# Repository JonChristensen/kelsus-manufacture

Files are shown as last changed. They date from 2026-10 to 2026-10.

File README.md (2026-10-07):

# The Kelsus Manufacture — open-source, 3D-printable watch movements

**Nobody has published a working, printable, conventional watch movement designed
as a platform for complications. This project builds them — in public.**

The movements are the road, not the destination. The destination is two
complications that don't exist yet in mechanical horology:

1. **A haptic metronome** — taps your wrist at an adjustable musical tempo,
   powered by its own dedicated mainspring barrel (the architecture of
   mechanical alarm watches like the Vulcain Cricket, pointed at a new job).
   This is **Caliber K2**.
2. **A world-class tide indication** — going beyond every existing tide watch
   (Corum, IWC, CVDK all model a single tidal constituent) by mechanically
   summing a second constituent — the "priming and lagging" of the tides —
   plus perigean spring tides via an anomalistic-month cam.

Everything is **parametric Python ([build123d](https://github.com/gumyr/build123d))**:
the CAD is code, every dimension traces to a parameters file, every design
decision is a reviewable git diff, and geometry is unit-tested in CI before
any printer wastes plastic.

Like a real manufacture, this repo holds multiple calibers sharing one
engine (`movement/` — cycloidal gears, the sweep solver, the spring model):

| Caliber | What | Status |
|---|---|---|
| [**K1**](calibers/k1/) | Time + moon phase; the proven base movement | **First physical build underway** — rev C is printing; dry-train assembly next (PETG flexures to follow) |
| [**K2**](calibers/k2/) | Time + the haptic metronome | Two-sided layout frozen; winding link solved (log 0023); parts stage next |

Scale: these are desk-scale movements (Ø170 mm mainplate) — watch architecture
at a size FDM printing genuinely masters, with a metal-transferable topology
(K2's target is a 44×15 mm wristwatch case). Proven precedent: [Christoph
Laimer's printed tourbillon](https://www.thingiverse.com/thing:1249221)
(Ø102 mm, runs).

The ocean — the tide complication's destination — lives in the frame itself:
K1's train bridge is a breaking wave, and the wheels spin on whirlpool spokes.

the wave bridge

## Build it

```bash
python3 -m venv .venv && .venv/bin/pip install -r requirements.txt
.venv/bin/python -m pytest tests/            # the geometry gate (runs in CI)
.venv/bin/python tools/export_print_kit.py   # K1 print kit -> exports/k1/print/
.venv/bin/python tools/render_previews.py    # PNG previews of every part
```

Print from [`exports/k1/print/`](exports/k1/print/MANIFEST.md): the MANIFEST
carries per-part orientation, support maps and quantities; the
[printing guide](docs/k1/printing-guide.md) carries the bench-proven Bambu
Studio settings. Curated, support-painted Bambu plates live in
[`exports/k1/print/plates/`](exports/k1/print/plates/README.md). Then follow
the [assembly guide](docs/k1/assembly-guide.md) — stage by stage, each with
its own inspection gate, from mainspring to a regulated tick.

## Repository layout

- `movement/` — the shared engine: cycloidal gear generator, sweep solver,
  spring energy model. Caliber-agnostic by rule.
- `calibers/k1/` — Caliber K1 rev C: parameters, layout solver, parts, dial
  side, the traced wave bridge
- `calibers/k2/` — Caliber K2: frozen brief + metal target, the two-sided
  layout, the one-crown/two-position winding link
- `attic/` — superseded generations, kept buildable and tested: the rev A
  storey tower, the rev B flatten, K2's round-plate era
- `exports/` — print kits and review STEPs, per caliber (latest per line;
  history keeps the rest)
- `docs/log/` — the engineering journal (decisions and why), one unified
  timeline across calibers; `docs/k1/` — build guides, milestones, registers
- `tests/` — the geometry gate: clearances, mesh ratios, stack heights,
  assembled poses. CI runs it on every push.
- `tools/` — exporters and massing/review builders

## Licensing

Two permissive licenses, chosen so anyone can build a business on these
movements without asking us or paying us.

- **Hardware designs** (everything under `movement/`, `calibers/`, and
  `attic/`, plus the generated STEP/STL geometry):
  [CERN-OHL-P v2](LICENSE), the permissive variant of CERN's
  open hardware license. You can manufacture the movement, sell it, modify it,
  and keep your modifications closed. It carries an explicit patent grant, which
  a copyright-only license like CC0 or CC BY does not, and that grant is what
  protects a functional mechanical design. No reciprocity, no share-alike, no
  obligation to credit us on the movement.
- **Tooling** (`tools/`, CI): [MIT](LICENSE-MIT).

This is a deliberately more open position than the current open watch movement,
[openmovement's OM10](https://openmovement.org/project/om10/). The OM10 is
copyleft (CC BY-SA 3.0): it requires you to engrave its calibre number on the
movement, requires your derivatives to carry the same license, and reserves the
production 2D/3D data for sale under its own purchase terms. This manufacture
asks for none of that. Take the geometry, put it in a product, sell the
product, and you owe us nothing.

## Follow along

Build-in-public links (site, TikTok, videos) land here as they go live.

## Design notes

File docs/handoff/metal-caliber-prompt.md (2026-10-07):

# Handoff prompt — design the 36 mm metal base caliber

*Paste everything below the line into a new conversation that has this repo open. It was written on Oct 7 2026 at the end of a long session on the plastic K1; the plastic work continues in a separate conversation. Keep both from editing the same files — see "Working arrangement".*

---

You are taking over the design of an **open-source mechanical wristwatch caliber in metal** from a conversation that spent four months building its 5×-scale plastic prototype. This document is the whole context you have: the goal, what exists, what was learned, what was decided, what is still open, and the plan. Read it fully, then read the repo files it points to, before proposing anything.

## 1. Who you are working with

Jon (jon@kelsus.com) is a self-described CAD novice who directs, prints and tests; you drive the CAD. He owns a Bambu Lab H2C printer (350 × 320 mm bed) and builds in public (GitHub, website, TikTok). His construction instincts about real watches — from studying the NH35, ETA 2824 and 6497 — have repeatedly out-corrected the model's; when he says a real movement does it another way, verify yours against the real caliber before defending it. His eyes are a required gate: every design step ends with an "inspect this" checklist and a rendered picture he can judge.

The memory directory for this project (loaded automatically as `MEMORY.md`) holds the standing lessons. Read it; the entries `feedback-target-is-watch-scale`, `k1-rev-b-flatten`, `inspection-gates`, `cad-workflow-choice` and `k1-revc-status` matter most here.

## 2. The goal, stated plainly

A **truly open, free-for-anyone wristwatch base caliber** — Jon's own design including the base, with no license strings, no branding requirement, no membership gate (OpenMovement's OM10 was considered and rejected on exactly those grounds). On that base, later, complications that do not exist in horology: a **haptic metronome** (Caliber K2's job; the metronome keeps its own barrel) and a **world-class tide indication**. The complications are years away and are not your job now. The base is.

"Open" for hardware means: every drawing free; every part either makeable from the drawings or a commodity anyone can buy from more than one source. Nobody — not independents, not most Swiss brands — makes hairsprings, jewels or mainsprings. So:

- **v1:** everything is Jon's except the regulating consumables, which are bought as a multi-source assortment.
- **v2:** Jon's own escapement and balance, once v1 keeps time.

## 3. Decisions already made (Oct 7 2026) — do not reopen without new evidence

| Decision | Value | Why |
|---|---|---|
| Size class | **36 mm** (6497-class), fits a 42 mm case at the floor, 43–44 comfortable | Complications need plate; main train stays near module 0.2; plastic model at a clean 5×; hand-fitting margin for a first-time maker |
| Beat | **4 Hz, 28,800 bph** | Industry sweet spot; the most open frequency on earth. 5 Hz was wanted and declined: f³ power cost, lubrication demands, and no multi-source 5 Hz assortment exists |
| Regulating organ, v1 | **ETA 2824-class assortment**: balance complete + hairspring, pallet fork, escape wheel, shock protection, jewels — made by ETA, cloned by Sellita (SW200) and Seagull (ST2130), stocked aftermarket | Design the balance cock, escapement positions and jewel seats so these parts drop in. A big plate with a small fast balance is normal manufacture practice |
| Power reserve | ≥ 40 h from a Ø16-class barrel; the metronome gets its own barrel later | 4 Hz with a big barrel lands 40–50 h |
| Thickness | base 5–6 mm; expect 13–15 mm cases once modules stack | Tell Jon before anything grows it |
| Plastic's role | a **5× kinematic model derived from the 1× design**, never the other way round | The old mistake was a print-first geometry with a "metal variant" that was the same Ø150 plate in brass — a clock nobody wanted |
| Source of truth | build123d code in git, parametric, with pytest gates and CI; export → render → look at the PNG before calling anything done | Memory: `cad-workflow-choice` |

## 4. What exists in the repo

Layout (`README.md` is current): `movement/` is the shared engine — `gears.py` (cycloidal wheel/pinion faces: `wheel_face`, `pinion_face`, hypocycloid gullets, BS978 addenda, backlash), `solver.py` (the station/sweep layout solver — read `docs/how-the-solver-works.md`), `springs.py`. `calibers/k1/` is the plastic K1 rev C (time + moon phase): `revc.py` (frozen layout, counts, `ESC_TUNE`, `TOOTH`, `WINDING`, the chirality chain), `revc_parts.py` (every part builder), `revc_dial.py`/`revc_dial_parts.py` (dial side: indirect minute via a 3-mesh transfer chain, motion works and a 59.0625-ratio moon train in dial-face recesses), `variants.py` (the print/metal dimension tables — see §6), `decor.py`, `wave_art.py`. `calibers/k2/` is the metronome caliber's brief and layout (Ø250 two-sided massing, winding link solved). `attic/` holds rev A/B. `tools/` holds the exporters (`export_print_kit.py` generates `exports/k1/print/MANIFEST.md` — never edit the .md), the STEP builder (`build_revc_movement.py`), and the **kinematic probes** that are the project's real instruments: `probe_escapement.py` (sections built solids to 2D with shapely and simulates the lock/unlock/tick with the wheel torque-butted), `probe_fork.py` (roller pin through the fork horns), `probe_click.py`, `probe_winding.py`. `tests/test_revc_parts.py` is ~100 gates run in CI (`.github/workflows/ci.yml`); as of Oct 7 the suite is 106 passed, 3 xfailed (the xfails record the broken keyless works).

Read, in this order: `README.md`, `docs/log/0016-rev-c-expert-brief.md` (how a brief is written and why top-down matters), `docs/log/0025`–`0028` (what the bench taught), `calibers/k1/revc.py`, `calibers/k1/variants.py`, `docs/how-the-solver-works.md`, `tests/test_revc_parts.py`.

## 5. The honest assessment of K1 as a watch caliber

**Architecture: right, keep it.** Two-plate construction; offset going barrel hanging from the plate with a bridge-web bearing; an interleaved two-plane train with a true 60 s fourth arbor; Swiss lever; keyless works with ratchet and crown wheel at the bridge plane; motion works and moon train in dial-side recesses with a retaining platform (only the hour wheel stands proud); a decorative bridge that is a real train bridge. Jon's corrections drove it there and it maps onto real construction.

**Proportions: plastic's, discard.** Every number was chosen to survive a 0.4 mm nozzle: module 1 teeth with 6- and 7-leaf pinions at the packing limit; a 16-tooth escape wheel at ~0.5 Hz on a 30 s/rev arbor; a 2:1 last stage; Ø2.5 pivots in printed cups and a shoulder-on-shelf endshake system with blind bridge bearings; a 14 g balance trimmed with M3 nuts; a fork with integral stones built to a print envelope; a PETG mainspring sized at PETG's strain limit; a pull-pawl click. None transfer.

**The gap: there is no 1× design yet.** `variants.py`'s "metal" entry is the Ø150 geometry with metal clearances and a 30-tooth escape wheel giving 1 Hz. A 1 Hz wristwatch is shock-sensitive and positionally unstable. The variant switch was meant to stop the project "getting married to the printable version and flying blind at the CNC handoff"; it never got a scale, so it guarded nothing. **Your first structural job is to make 1× the source of truth and derive the print model from it.**

**Train arithmetic you will redo.** K1 counts are `(60, 10, 56, 7, 45, 6, 36, 18)` = barrel 60 → center pinion 10 (6:1, center at 1 h/rev) → center wheel 56 → third pinion 7 (8:1) → third wheel 45 → fourth pinion 6 (7.5:1, fourth at 60 s/rev) → fourth wheel 36 → escape pinion 18 (2:1). Barrel-to-escape is 720:1. At 4 Hz the escape wheel's revolution time is set by the assortment's tooth count (take it from the real part — measure a 2824/SW200 or use published service data; do not trust memory for the 2824's counts, lift angle or center distances), and the barrel-to-escape ratio becomes roughly 4,000–6,000:1. Keep center at 1 h and fourth at 60 s; most of the new ratio lands in the fourth-to-escape stage, which real calibers run at a finer module than the rest of the train. Set a pinion leaf floor of 8. The K1's packing-limit lesson (log 0025: Z3 ≤ Zm + p3 − pm − 6 at module 1) was a module-1 problem; re-derive at the new modules with the same solver and gates.

## 6. What transfers from the plastic work (keep) and what does not (drop)

**Keep — scale-free:** the architecture; the solver and its station sweeps; `movement/gears.py`; the kinematic-probe method (section the built solids, simulate, assert on the simulation — never on a static pose or a volume tolerance); the gate discipline (global swept-volume collision gates before any part modeling; assembly-path gates; "would this ship in metal?" review at every milestone); the chirality chain and winding-direction derivation in `revc.py`; the keyless-works and motion-works mechanisms; the moon train ratio.

**Kinematic lessons that transfer verbatim:**
- Lever escapement draw rule (log 0027): draw exists iff the stone's locking face has its inner end *upstream* of the contact, which requires a tooth whose body sits behind its tip with face rake greater than the draw angle; the face must pass through the tip-flat's downstream corner; test clearance with a real point-in-tooth test, not an envelope radius. An escapement with "lock reserve 0.04 mm" is an escapement with no lock. With a bought assortment you inherit a correct escapement, but the probe is how you verify your plate puts it at the right centers.
- A click must be a pull-pawl (pivot on the far side of the contact, inside the tangent) or it will not hold (log 0027).
- A relaxed-printed spiral mainspring is the wrong model of a steel one — but two things carry: the spring's hand must match the arbor's winding direction (a spiral tightens when its inner end turns *against* the direction its coils run outward), and the outer anchor must resist an **inward** pull unless the spring is reverse-curved like a real one (log 0028). A steel mainspring is reverse-curved; a plain hook works. Still: design the barrel hook, not just the barrel.
- Pivots: nothing under Ø2 in plastic survives Jon's hands; at 1× the analog is "every pivot, shoulder and stop is a standard watch feature with a standard tool to make and measure it."
- Endshake and depthing are *adjusted at assembly* in metal; design the adjusters (bushings/jewel settings that can be moved, eccentric banking, movable stud) rather than freezing everything in plate geometry as the plastic did.

**Drop — plastic-only:** every dimension in `revc_parts.py`; `ESC_TUNE`, `TOOTH`; the printed-jewel endshake system; the 16/30-tooth escape wheel; the PETG spring ladder and the cover-pin anchor; the pull-pawl click's geometry (keep its principle); the nut-weighted balance; the cabochon/printed endstone; the keyless works as drawn (three measured faults, tracked by the `test_keyless_*` xfails).

## 7. The process lessons (these cost months — honor them)

1. **Design top-down from hard targets.** Rev B was built by accretion under per-screenshot corrections — locally right patches, globally wrong architecture (log 0016). Write the brief first: size, height, beat, reserve, assortment, jewel count, screw and stem standards, DFM rules. Then layout. Then parts. Gate everything behind a global collision test from day one.
2. **Never let a test fixture become architecture.** The M1 test-stand spider became rev A's frame.
3. **Measure before redesigning.** Every bench round that went well started by measuring the fault (coupons, probes, photos of the break); every one that went badly started with a guess. Keep the probe-first habit.
4. **Gates that don't simulate lie.** Static-pose gates, volume tolerances and sign-only heuristics each green-lit a real defect. A gate should run the mechanism.
5. **"One fused solid" is not "printable/machinable."** Point-contact welds and 0.6 mm isthmuses passed the solids==1 check. Add erosion/wall-thickness probes and, for metal, DFM gates (minimum wall, EDM inside radii, reamable holes, standard threads).
6. **Verify the edit landed.** Heredoc edits silently no-op'd more than once and the suite green-lit old geometry. After any geometry change, measure the built solid.
7. **Jon prints from saved slicer projects that embed old meshes** — the metal analog is vendor files: every quote package must be generated from the tagged code, never hand-edited.

## 8. The plan

**Phase 0 — the brief** (first deliverable, `docs/<caliber>/brief.md`, written like log 0016): 36 mm, ≤ 5.5 mm base height target, 4 Hz, 2824-class assortment with its real measured parameters, ≥ 40 h, barrel diameter, jewel count and sizes (standard jewel ranges — verify the standard, don't assume), shock protection unit, stem/crown thread standard, screw thread standard, plate and bridge materials (brass or nickel silver), DFM rules (minimum wall ≈ 0.3 mm in brass; wire-EDM inside radius from a 0.1 mm wire; reamed pivot holes; no feature a job shop can't quote), and a reserved footprint for the metronome module and its barrel (K2's brief in `docs/log/0020` and `calibers/k2/brief.py` say what it needs). Jon gates the brief.

**Phase 1 — the variant system gets a scale.** Restructure so the 1× geometry is primary and the print variant is "1× scaled by 5 with print fits and a print-tuned escapement end." The plastic model can't run 4 Hz in PLA; it validates the barrel, train to the fourth wheel, keyless and motion works at 5×; the escapement end is validated at 1× in metal with bought parts. CI builds and tests both.

**Phase 2 — train and layout** with the solver: new count set, pinion floor 8, finer module at the escape end, barrel sized for reserve, assortment placed by its real center distances. Global swept-volume gates before any part.

**Phase 3 — parts** in dependency order (plate and bridges, barrel and arbor, train arbors and wheels, keyless works, motion works, balance cock around the assortment), each with assembly-path gates and DFM gates. A 5× print of each subsystem as its kinematic first article.

**Phase 4 — the vendor loop.** Rented precision, not a factory: quick-turn laser/waterjet or photochemical etching for flat parts (cams, levers, springs in 0.1–0.5 mm stock); wire-EDM job shops for steel parts; micro-machining shops (medical-device suppliers) for brass plates/bridges in 5–50 piece runs. First purchase is one plate, one wheel and one lever sent three ways to learn the vendors (~$300). A desktop mill only if that round shows a weekly bottleneck. Jon also needs an ST36/6497 and a watchmaker's bench kit to learn stripping and fitting — the human half of the loop. Research the vendors with current prices and lead times before recommending any; the previous conversation gave ballparks only.

**Phase 5 — fitting and timing.** Assemble, adjust endshake and depthing, time on a timegrapher (rate, beat error, amplitude in six positions). Target ±20 s/day for v1; COSC-grade is a v2 ambition that depends on the regulating organ, not the plates.

## 9. Open decisions to settle with Jon in the first exchange

- Caliber name and directory (suggestion: a new `calibers/<name>/` with its own `docs/<name>/`; K1 stays the plastic lineage).
- Base height target and whether center seconds or small seconds (K1 has a 60 s fourth arbor; small seconds is simplest).
- Hand-wound only for v1 (yes, unless he says otherwise).
- Which real 2824-class movement to buy and measure for the assortment's parameters.
- Whether the moon phase stays on the base or becomes a module.

## 10. Working arrangement

Jon is continuing the **plastic K1 rev C** in a separate conversation on `main` — that is its own feat and not yours. **Work in a git branch or worktree** (e.g. `metal-caliber`) and add new directories rather than editing `calibers/k1/`, `tools/` K1 exporters or `tests/test_revc_parts.py`. You may extend `movement/` if K1's tests still pass. Commit or push only when Jon asks. Nothing from the plastic session was committed as of this handoff; ask Jon to commit `main` before branching so the worktree carries the current state. Memory lives in the per-project memory directory and is shared between the two conversations; note anything durable there under a name that says which caliber it concerns.

## 11. Todos handed over from the plastic session (not blockers; do them early)

1. **Stop tracking the STEP in git.** The rebuilt `exports/k1/revc/movement_r11.step` is 122 MB — over GitHub's 100 MB file limit — so it was left uncommitted; the committed copy is the older 66-component one (52 MB). Even at 52 MB it is a bad git citizen (every rebuild adds a tens-of-MB blob to a public repo's history forever). Add `exports/**/*.step` to `.gitignore` (keep the small `massing_r6.step` if wanted), keep exporting locally, and publish the STEP as a GitHub release asset or CI artifact. Regenerate it any time with `PYTHONPATH=. python tools/build_revc_movement.py`.
2. **Build gear-tooth flanks as splines in `movement/gears.py`.** Measured Oct 7: every toothed wheel is 8–11 MB of STEP because the coda-4 tooth form (24-point flanks, hypocycloid gullets) is a polyline — one planar face per point. One B-spline face per flank shrinks the STEP roughly tenfold, leaves the STLs unchanged within tolerance, and gives the metal caliber the smooth curves CAM wants. Shared engine: run the full suite (`python -m pytest tests/ -q`, ~12 min) and K2's tests after; coordinate with the plastic conversation, which owns K1's exports.
3. `exports/k1/print/barrel+winding-group-k1.3mf` is a slicer scratch project tracked from before the ignore rule (only curated plates in `exports/k1/print/plates/` are meant to be tracked). It is modified and uncommitted; either `git rm --cached` it per the rule or Jon says to keep it.

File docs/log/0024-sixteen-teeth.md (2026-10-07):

# 0024 — Sixteen teeth: the escape wheel meets the nozzle

**July 12, 2026.** Jon, holding the printed escapement: the 30t wheel's
teeth are too fine for a 0.4 nozzle, and a 12t wheel he found online
(a published printable clock) shows what forgiving plastic escapement
geometry looks like. He asked the right question: *do all escape wheels
have 30 teeth?*

They don't. Watches run 15/20; our 30 was integer convenience
(30t × 1 Hz = 30 s/rev = the seconds-true fourth), not a print decision.

## The discovery that made it cheap

The escape wheel meshes nothing — the train drives its arbor's 18t
pinion, so the wheel's tooth count is **beat rate only** (f = teeth/30
Hz). And the fork's stones, frozen ±39° in the printed plate, span 3.47
tooth-pitches at 16t — within 0.03 of the deadbeat half-integer. So 16
teeth drops in with **no mainplate, bridge, fork, or train changes**:
pitch 22.5°, tooth arc 6.3 mm — the same proportional tooth room as the
12t reference. Volume-probed: capture humps alternate at 0.48 pitch,
free margins wider than 30t ever had (60% vs 46% of cycle).

15t and 12t would need the pallet pivot moved — a plate reprint. 16 is
the only chunky count the existing plate supports. Taken.

## Paying for the beat: 0.53 Hz

f² ∝ k/I must shrink ×0.284. Split three ways, because each lever alone
runs out of room:

- **Hairspring ×0.55** — h 2.5→1.75, coils 11→13. More coils don't fit:
  past 13 the first coil walks onto the collet lip and the beat slit
  would sever it (found by arithmetic before it was found by bench).
- **Printed rim ×1.26** — whirlpool windows stop at r14 (was r20).
- **Timing screws ×~1.55** — 6× M3×8 steel in the r23 rim holes. The
  holes were always called "timing holes"; now they earn the name.
  Screw length/count = the bench rate trim, which a printed movement
  needs regardless — every spool's modulus is different.

Wired as `Variant.esc_teeth` (print 16, metal 30): the metal world keeps
its 1 Hz watch beat; plastic gets teeth it can actually print. The
escapement gate test now checks capture-hump alternation generically
(the old free-set-disjointness only held at 30t geometry).

## Cost recorded honestly

Jon's already-printed 1 Hz hairsprings are obsolete for the print
variant (tuned 3.5× too stiff), as is the light balance wheel. Reprint:
escape_wheel ×3, hairspring ×3, balance_wheel ×1. Tooth form and count
both derived by measuring the reference part — parameters, not mesh.

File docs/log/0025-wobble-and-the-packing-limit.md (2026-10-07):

# 0025 — Wobble, and the packing limit hiding in the third wheel

**August 3, 2026.** Bench report from the first train assembly: two
wheels spin, three sometimes, four locks — every time. Jon, watching
from the side: the wheels visibly wobble. Holding one wheel and rocking
its mate gives about a degree of play each way, and the barrel–minute
mesh is looser than minute–third.

## The numbers agree with his fingers

Designed backlash is 0.30 mm circumferential — about **0.6° total** at
the minute wheel. Jon feels ~2°. The extra ~1.4° ≈ 0.7 mm at the pitch
line, which is the bore clearances talking: 0.20 radial per pivot
(pre-measurement guesses, set before the printer's real accuracy was
known) → 0.4 mm diametral per arbor, two arbors per mesh. The
barrel–minute mesh is loosest because it stacks **three** interfaces:
drum-on-arbor, arbor in its 2.0-deep plate cup, arbor in the bridge.

Why length kills the train: over the ~12 mm plate-to-bridge span, 0.4 mm
per bore lets an arbor cock ~3–4°, swinging a Ø56 wheel rim **±1 mm
axially — against 0.25 mm of designed air between gear metal and its
plane band**. Every station added is a new neighbor for a tilted rim to
rub, while torque falls ÷360 by the fourth pinion. Two wheels shrug;
four stall.

## The recount that refused to pack

The obvious deeper fix: the 45/6 third–fourth mesh is the classic
low-leaf binder, and (56/7)·(60/8) = 60.000 exactly — an 8-leaf fourth
pinion with the fourth wheel, escapement, and 0024's sixteen teeth all
untouched. The layout solver said no. Not "no room at this azimuth" —
**zero placements at any grid step**, because the third wheel (plane A)
must clear the minute *pinion* (plane A) across the fixed minute–third
center distance:

    Z3/2 + 1  ≤  (Zm + p3)/2 − (pm/2 + 1) − 2   →   Z3 ≤ Zm + p3 − pm − 6 = 45

The train was already **at the packing limit**. 45/6 was never integer
convenience — it's the biggest third wheel this architecture holds at
module 1. Every ≥8-leaf recount pushes some wheel past 60t and hits the
same wall (or the barrel-arbor cap that froze Zm at 56). Filed under
things the solver knew before we did.

## The coupon kit (exports/k1/print/coupons/)

Measurement before commitment — `tools/export_fit_coupons.py`:

- **fit_ladder + fit_pin**: the real blind bushing (Ø2.6, 3.0
  engagement) at six clearances, 0.05–0.20. The tightest tick a pin
  spins dead-free in becomes the print `pivot_clearance`.
- **mesh_jig + six test gears**: 45/6, an 8-leaf 60/8 *reference*
  (packing-blocked as a recount, kept as the control), and 56/7 — each
  at center distance pinched −0.25 / nominal / spread +0.30. Pinch is
  what bore slop does dynamically; the decisive cell is pinch on the
  6-leaf.

Decision table: 45/6 fine at nominal, binds only at pinch → tightened
fits carry rev C. 45/6 binds at nominal while 60/8 stays sweet → leaf
count is the wall, a rev D architecture question. Everything binds at
pinch, even 8 leaves → module 1 itself is marginal on FDM and the
scale-up conversation reopens — as a *module* change in code with
clearances held absolute, never a slicer scale (which multiplies the
very slop we're chasing and breaks every M3 bore).

## Coupon results (same day — Jon's bench)

**Ladder:** tick 3 (0.11) spins dead-true for one pin; 0.14–0.20 wobble
visibly, with 0.20 falling out of its bore on a spin. The second pin ran
perfectly even at tick 1 — **printed pivots vary ~2 ticks (±0.03 r)
part-to-part**, so 0.11 is the design value and the bench rule is:
spin-test every arbor, spares absorb outliers.

**Mesh jig:** all nine cells turn smoothly — even pinch on the 6-leaf,
even fast. Spread shows lash and a whiff of jump-out, nothing more. Jon
then caught the instrument's flaw: with slack in the jig bores, drive
torque's separation force parks both pivots on the loose side, so a
drilled pinch relieves back toward nominal — the cell tests *entering*
pinched geometry, not sustained pinch. Caveat now lives in the jig
README. The same physics runs in the movement, and it points the right
way: a driven train self-biases toward spread, which the jig showed to
be benign.

**Verdict: the mesh was never guilty. The fits were.** And the plane-air
arithmetic agrees with the symptom pattern: cross-plane metal-to-metal
air is 1.0 mm; at 0.20 fits the ±1.05 mm tilt excursion just reaches the
neighboring plane (why three wheels *sometimes* ran), at 0.11 it's
±0.55 mm — clear by nearly half a millimeter.

`pivot_clearance` print = **0.11** (variants.py, measured comment
attached). All 91 gates pass; kit re-exported; plate bushings verified
Ø2.82 in the STL.

## Cost recorded honestly

The clearance lives in more bores than the plate: reprints are
**mainplate, wave bridge, drum + cover (arbor bores), crown wheel (stud
bore)** for the train, then **bay strap + balance cock** with the
escapement wave 0024 already ordered (escape wheel ×3, hairspring ×3,
balance wheel), and the dial-side gears whenever that stage assembles.
Train arbors are innocent — reprint only bench-culled outliers.
`Variant.endshake` turned out to be consumed by nothing in rev C —
axial float is baked into the ZC bands — so the pivot bore is the whole
fits story. The 0.20 guess is retired by measurement, which is how it
should have been born.

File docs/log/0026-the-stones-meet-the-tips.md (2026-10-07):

# 0026 — The stones meet the tips: rebuilding the pallets for the wheel we actually print

**August 11, 2026.** Bench photo from Jon: pallet fork and escape wheel
assembled on the plate, one stone in a tooth gap, "not enough clearance
for the mechanism to *tick* back the other direction when one prong is
engaged." The exit stone is sitting ON TOP of a tooth — tip to tip.

## The probe that replaced squinting

Volume-threshold pose checks had passed this geometry, so the first
move was a better instrument: `tools/probe_escapement.py` sections the
real solids into 2D polygons and *runs the tick* — wheel torque-butted
CCW against the lever while the fork sweeps banking to banking, recoil
allowed. Ground truth per pose, ~40 s per run.

First run, old geometry: the tooth released the entry stone at 4.8 deg
into the 13 deg fork swing, and from there **neither stone gated the
wheel** — it free-ran more than a full pitch (the probe measured 24.5
deg) with the exit stone still 1.7 mm away. A free-running wheel lands
at random phase; sometimes that phase is a tooth top under the exit
stone, which is exactly Jon's photo.

## Root cause: 0024 changed the contact, the stones never heard

The July tooth re-cut (log 0024) made the wheel touch stones with
**tips only** at r16. But `lever_layout_c` still placed the stones by
the flank-era rule — working faces at `r_esc - sin(lock) - 0.4` ≈ r15,
a full millimetre INSIDE the tip circle, where a tooth tip can never
rest. The tips butted the stones' radial *backs*, the lock was
accidental, and the deadbeat handoff didn't exist. The old gate test
actively asserted the defect: "at neutral the wheel passes free" — a
free wheel at neutral IS the open gate.

## What the rebuild learned (each item probe-caught, in order)

1. **Embrace re-phased to the half-integer.** Contact azimuths now sit
   3.5 tooth pitches apart (±39.375 deg at 16t). P does not move — the
   plate survives; only the lever reprints.
2. **The deadbeat direction here is radial.** E–contact–P is ~94 deg,
   so an arc about P (the classic deadbeat locking face) is nearly
   radial about E. The locking face is that chord, draw-tilted, crossing
   the tip circle at the contact.
3. **The arm had to move.** Tip-contact stones sit ~1 mm closer in; the
   old straight boss-to-stone arm chord put its band edge INSIDE the tip
   circle — the wheel butted the *arm* 10 deg before the face. The arm
   now routes to a waypoint at r18.4 **in the engaged frame** (the
   banking swing plunges the whole side ~1.5 mm; a route laid out at
   neutral dips into the wheel at the banking) and welds at the face
   top. A weld hull that merely *touched* the corner left the stones as
   disconnected solids; the weld point now sits 0.45 inside the body.
4. **The impulse ramp is a trace, clipped by the real tooth.** The ramp
   is the path of the tooth tip in the stone frame under a chosen
   schedule (fork rides 6.5 deg past unlock, wheel advances 1.25 deg
   per fork deg). The printed tooth's hook back is a 3-chord polyline
   that bulges above the smooth t^0.6 form — the nose had to tuck
   2.64 deg downstream of the rest azimuth to clear it, and the ramp's
   coupling was flattened until the trace hugs the hook with ~0.15 mm
   to spare.
5. **The catch lands on the ramp, and that's the budget.** With lift at
   0.228 mm/deg and teeth only 2.8 mm deep, the wheel cannot stay
   coupled to within 1.7 deg of the far banking — a free flight is
   structural. The half-pitch spends as: ~2.6 deg face creep during
   unlock, ~8.1 deg coupled ride, ~5.8 deg flight, then the catch eases
   the wheel BACK ~6 deg as the fork seats (the plunging ramp pushes
   the caught tooth upstream). That retrograde is the efficiency debt
   of this architecture — cheap on the bench (back-driving the train
   is nearly free), a real question for the balance-driven stage.

## Jon's second catch: the stones were about to snap off

Same day, from the *render*: "how are those teeth connected to the
fork? They look like they might break right off." He was right, twice
over. The first weld hull touched the stone at a single geometric
point — OCC fused it into "one solid" that was two parts in every way
that matters. The fix-of-the-fix pulled a weld point 0.45 mm inside
the stone, which passed the one-solid check but necked to **under
0.1 mm** — sub-nozzle, unprintable, unsnappable only because there was
nothing there to snap. A second attempt with two pad points left a
0.6 mm isthmus.

The instrument that settled it: an **erosion probe** — shrink the
mid-body cross-section inward until it separates; twice the surviving
radius is the narrowest load path. The shape that passes: the stone's
back is now a **convex bulge from fin peak to face top at r17.4-18.0**,
territory the tooth tips (r16.0 exactly) can never reach at any pose,
and pose-safe against the bay wall because |pad − P| never changes.
The arm hull welds onto two anchors inside that bulge. Narrowest
bridge: **1.3 mm** plan × 2.1 thick ≈ 2.7 mm² — versus tenths-of-a-
newton working loads, and safe against tweezers and support-peeling.
The one-solid check and the tick sim both stand unchanged.

## The numbers, frozen (print variant, probe-verified)

Rest: tooth land-corner ON the locking face at r15.95, 0.2 deg off the
designed azimuth. Advance per half-swing: **11.24 / 11.26 deg** against
a half pitch of 11.25. Longest free run 5.8 deg; catch retrograde 6.2;
no jam, no runaway, cycle repeats at exactly one pitch. The gate test
now runs this simulation as the contract (shapely added to
requirements); the neutral-free assertion is inverted — at neutral the
wheel must butt within one pitch.

## Coda: one M2 screw for the whole movement (Aug 15)

Jon's fastener box turned out to be M3; the six M2s were never
ordered. The docs said "M2 self-tap ×6" — three lengths across three
parts, and the wrong *type* if bought literally: the pilots (Ø1.6–1.8)
want a **thread-former** that displaces plastic, not a sheet-metal
self-tapper that shaves it. Finding one at retail was the surprise:
genuine M2 PT/Delta-PT screws for plastic are a 5,000-per-carton
world (Fastener SuperStore, Monster Bolts) or dried-up 100-packs (US
Micro Screw's Amazon storefront). McMaster's M2 shelf holds only
Taptite® — thread-forming *for soft metal* — but a tri-lobular
Taptite is a thread-former, and in 6 mm of printed plate the narrower
flank is irrelevant. **McMaster 94209A343, M2×6, pkg 100, $9.** Ordered.

It comes in ×6 only. Rather than three lengths and a "which goes
where" trap, the parts were made to fit the screw:

- **dial platform** ×3: plate pilots 2.0 → **5.5 deep** (three sites
  probed solid to depth; 1.0 roof, tip air 0.3).
- **click** ×1: the bridge web is 1.3 thick — the click's screw only
  ever had 1.3 mm of thread. A **r2.4 boss now hangs under the web**
  to z11.6 (0.6 over the drum top; no plane-B sweep reaches that XY —
  probed) and the pilot runs through: **4.4 mm of thread**, tip flush.
- **bay strap** ×2: the interesting one. The near foot's pilot is
  **capped at z2.5 by the dial-side solver** (moon B2 pockets 1.9 deep
  + 0.6 web — the old 2.5 was never arbitrary), so the plate could not
  be deepened there. And investigating headroom found a latent bug:
  the old service test checked the screw *shank* radius (1.1) against
  the balance rim, not the *head* — a Ø4 pan head at the old feet
  (r27.5 from B) sat **0.5 mm inside the r26 balance rim**. Both feet
  moved to **20.8 from P** (r28.45 from B) and grew **r2.2 × 1.7 head
  bosses**: heads clear the rim by 0.25, and the raised bearing face
  lets the ×6 land 0.3 above the capped pilot. The service test now
  checks the head radius. Strap and plate reprint together.

The fasteners are now **parts in the build**: `m2x6_screw_c()` posed at
all six sites goes into the STEP, and a new gate asserts each screw
touches only what it fastens and threads ≥3.5 mm into its anchor. That
gate immediately found the second latent issue: the three platform
screw heads stand 1.4 proud of the platform's dial face, straight
through the 1.0 dial sheet. The sheet now has Ø4.6 clearance holes;
**three pan heads show 0.3 proud in the dial face** — the honest cost
of holding the platform from the dial side with the plate 6.5 thick.
A flush dial wants countersunk heads and a thicker sheet: aesthetics
pass, Jon's call.

## Coda 2 (Aug 19): the fork that parks anywhere — and why

Jon's video: the Aug-16 fork assembled, wheel spinning **free with the
fork parked at neutral**. The probe had passed it. Both things are
true, and tracing why took the day.

1. **The mid-swing gate was closed by 0.3 mm** — the gate test asserted
   a sign, not a margin; the 0.11 pivot fit erases 0.3 mm. Lesson
   taken: the test now measures intrusion.
2. **Far worse: the escapement has no draw.** New probe check — butt
   the wheel at a banking, move the fork 0.1° off its pin — shows the
   wheel advancing *freely* at both bankings. Nothing pulls the fork
   home; that is *why* it parks anywhere, and it means a balance would
   never keep it running. The tick sim drives the fork externally (like
   tweezers) and never asked whether it stays put.
3. **Root cause, found by stepping the wheel into the stone and naming
   the first contact:** it is the **hook-back of the approaching tooth,
   6° ahead of its tip**, landing on the stone's ramp at r14.3 — before
   the tip ever reaches the locking face. The tooth's back sweeps
   forward ~13° from the land down to the root, so **anything the stone
   dips below r16 downstream of its face is met by the tooth's back
   first.** Envelope, measured: 0.5 mm max intrusion 2° downstream,
   1 mm at 4°, 1.8 mm at 8°. Every ramp I built (ride 4–10, couple
   0.4–1.25, floor 13.8–15.3, both draw signs, narrow and wide) violated
   it near the face; the "lock" in every variant was the stone's belly
   on a tooth back — an impulse-direction surface, hence zero draw and
   a hair-thin free window.
4. And the mid-swing gap follows from the same envelope: a ramp that
   respects it at banking sits ~1.5 mm higher at neutral (lift ×6.5°),
   i.e. at or outside r16. **With this tooth form one stone cannot both
   respect the hook-back and reach the wheel at neutral.**

Two smaller bugs fixed on the way: the nose was a separate tucked point
that made the stone's underside a V (flank-on-apex catch) — it now lies
on the face line; and the fin lean is capped so narrow stones don't
self-intersect.

**Open design point — Jon's call, not taken here:** (A) reshape the
tooth (steeper back right behind the land) — wheel + fork reprint, real
margins on draw, window, and mid-swing; (B) keep the wheel, build the
ramp to the envelope — face lock with draw, but ~0.2–0.3 mm mid-swing
reach and a fork that parks free on the bench; (C) both. Recommended C.
ESC_TUNE is held at the Aug-16 printed values as the baseline until
then; the probe carries the new draw/window/depth instruments.

## Coda 3 (Aug 19, later): Option C — the tooth was backwards

Jon chose C (reshape the tooth too). What followed corrected coda 2
in three places, and they're worth stating plainly because each one
cost hours:

1. **The tooth was mirrored.** The July wheel's raked locking face
   was on the tooth's *trailing* side (rising from the gullet up to
   the tip, in the direction of travel) with the land and back
   *ahead* of the tip. A stone waiting ahead of the tooth is therefore
   always met by the tooth's back first and its tip last. "Steepen
   the back" (coda 2's plan) can't fix that; only putting the face on
   the **leading** side can. Done: in travel order the tooth is now
   tip → 20°-raked face falling to the root → root → steep back rising
   → next tip. The tip leads; nothing of the tooth is ahead of it.

2. **Draw is a force, not a trap.** My draw test asked "does the
   fork have to make the wheel recoil to leave its pin?" — no working
   escapement satisfies that (the fork must unlock). It returned zero
   for every geometry including ones that were correct, and sent me
   chasing face angles for an hour. The right test is the torque of
   the resting tooth's push on the locking face about P: it must carry
   the fork into its banking. `Scene.draw_torque` now; +3.4 on both
   stones.

3. **A sharp tip is not a tip.** The design passed everything with a
   mathematically sharp tooth and then, with a print-realistic r0.2
   rounding, the round slid *under* the face: rest fell to r15.26 and
   draw went *negative*. The tip is a **0.2 mm flat** now (prints
   faithfully, gives the face a defined edge), the gate runs the whole
   contract again on an r0.1-rounded wheel, and the stone's lock
   depth below the tip circle is *solved* against the tooth envelope
   (`hook_back_r`, which now correctly describes both sides of the
   tip) instead of guessed — it resolves to 0.04: the flat locks on
   the face right at the tip circle, the 2.4 mm of stone inside the
   wheel at banking is the real lock depth. Any deeper face puts the
   foot where the tooth's flank arrives first (probe-verified: forced
   0.45 → flank-on-foot, fragile).

Also: `face_rake 20°` (was 38; the 0.33 mm/° fall at 38 reached any
sub-r16 stone material 1.2° ahead of the tip), stone impulse bevel
built as the tip trace *clipped to the tooth envelope* (hugs the tooth
from outside at banking; the tip climbs it as the fork lifts),
`ride 10.5 / couple 0.9` (probe knee: 9 → mid +0.34, 10.5 → +0.41,
12 → the bevel turns anti-impulse and drives the wheel backward).

**Frozen (probe, print-realistic r0.1):** tip on the face at r15.96 ·
draw +3.38 / +3.42 · mid-swing intrusion +0.40 (was 0.28 on Jon's
fork, 0.3 mm of which the 0.11 pivot fit ate) · free window at banking
9–10° (was 0–1) · tick 11.24 / 11.26 per half-swing against 11.25 ·
robust to r0.1 corner rounding (same numbers). Tooth 0.8 mm wide at
mid-depth, 2.4 thick — prints at 0.4; it is a ratchet-style sawtooth,
which is what a deadbeat wheel looks like.

## Coda 4 (Aug 22): the winding stage was never a ratchet, and the
## train gets its textbook teeth

Jon, at Stage 5: which way does it wind? And two bugs: the click
cannot stop the ratchet, and the crown wheel's underside teeth are
hollow at 9 o'clock, solid at 3.

**Direction, derived not guessed:** the documented train chain puts
the drum at CCW (bridge view) running, so the spring torques the
arbor CW and the click must block CW. **Winding = ratchet CCW seen
from the bridge**; the crown knob, viewed from above, also turns
counter-clockwise. Now in the assembly guide.

**The click bug was total:** `ratchet_c` built its teeth with
`wheel_face(24,24)` — a symmetric involute spur. No click locks
symmetric teeth; the wedge cams out both ways. And the crown moire
was a vernier: 23 underside slots against a 24-tooth rim drift 0.65
deg/tooth, so once around the wheel the slots pass from under-gap
(solid teeth) to under-tooth (hollowed). Both wheels are now a
matched SAW pair (tips r13, roots r10.7): tip flat, near-radial
cliff, ROOT LAND, then a CONVEX ramp — steep below r12 where the
crown tip nests, shallow (58 deg) above where the click rides. Three
probe-caught corrections en route: the first saw was mirrored
(slipped at letdown, jammed winding); without the root land the pair
could not nest at ANY phase (0.68 mm3 minimum overlap); a straight
ramp made winding stiff (30 deg at the click's riding depth). Slots:
24, phase-locked under the gullets — every tooth identical and
solid. The crown carries a -0.75 deg phase trim centering the
clean-nest plateau. Verified behaviors, now a permanent gate
(`test_revc_winding_is_one_way`): letdown butts a 7.7-deg cliff in
0.1 deg; winding cams a 58-deg ramp; crown CW drives ratchet CCW
59.5/60; reversed crown hard-stops within one tooth (by design —
the guide says don't force it).

**The train's fidelity pass** (Jon's bench: "still a little sticky",
plus his textbook cycloidal-pair diagram): movement/gears.py now cuts
TRUE hypocycloid dedendum flanks (the deep hollow gullets of the
reference — the old straight-radial shortcut needed a 0.35 root
relief to avoid scraping), 24-point flanks (12-point facet flats were
part of the friction), eased tip corners, FULL semicircular pinion
noses (the 0.65 squash undercut the roll), and BS978 addendum 0.85
on wheels driving 6-10 leaf pinions — the approach-side scrape Jon
felt is exactly what an oversized addendum on a low-leaf pinion does.
Same module, same center distances: no plate or layout change.

**The escape-skip worry, quantified:** stretching the fork away from
the wheel by the full worst-case bore-slop stack (+0.32 mm, both
pivots hard against their cup walls) costs the mid-swing gate only
0.41 -> 0.33 mm — no static skip. Residual risk is 3D arbor tilt +
dynamic bounce: bench rule is to spin-select the fattest-pivot fork
and escape arbor for those two stations; next plate revision drops
the E/P cup clearance to 0.06 (logged here so it isn't folklore).

## Coda 5 (Aug 23): Jon's question that found the missing half of the
## bearing architecture

"I've been surprised that a big source of friction is the gear plates
rubbing against each others' faces and/or the main plate or bridge. In
metal movements the gears were suspended by their pivots in jewels.
Does our design anticipate this?"

The probe's answer: partially, and the missing half was load-bearing.
Measured axial float per train arbor, and what stopped it: minute
0.45 mm up, stopping as the 56t WHEEL FACE flat on the bridge web
(52 mm^3 of contact); third/fourth/escape ~0.45 up onto the bridge,
~0.18 down onto the plate. On the desk stand the movement's axis is
horizontal — gravity doesn't even pick an end — so every arbor wanders
its full float until a wheel face leans on something at r10-28, which
costs ~40x the friction of a shoulder stop at r~1. The tell: the
variant system had carried an `endshake` parameter that log 0025
noted was consumed by NOTHING. The plane-band system kept gear faces
off other GEARS; nobody built the axial bearings.

The fix is the metal principle, printed — and not a restart:

- **stepped bridge bearings**: r1.35 guide bore to a SHELF, then
  r0.85 for a reduced arbor tip; the pivot's shoulder annulus meets
  the shelf = the up-stop at small radius. (First cut failed: the
  1.2-tall lead-in cone stayed wider than the guide bore for its full
  height and swallowed the shelf — probe-caught; the lead-in is now a
  0.5 chamfer.)
- **arbor tips**: Ø1.4 x 1.2 reduced top tips (shoulder at z15.0);
  Ø1.2 nose bosses on the lower pivots so the down-stop on the
  existing cup floors is near-axis; the minute arbor — the one with
  no cup floor, whose down-stop was WHEEL-ON-DRUM — gets a r1.9
  collar riding its plate bore mouth.
- **endshake CONSUMED at last**: print 0.35 (must sit under the
  smallest face gap, 0.45), metal 0.10 — same architecture, tighter
  numbers. That is the metal-transferability answer: yes, by
  construction now.

Verified: every arbor floats 0.38-0.41 total and stops ON-AXIS with
~0.2 mm^3 shoulder/nose contact, both directions. Permanent gate:
`test_revc_arbors_float_on_shoulders_not_faces` (it would have failed
the old design at every arbor). Barrel arbor left as-is: its 0.07
float is bounded inside the drum by design.

**Coda 5 addendum — the cabochon pocket was waiting.** Jon's "beads"
turned out to be Ø4 x 2.09 flat-back garnet CZ cabochons — and the
cock has carried a decorative "cabochon pocket" since rev B (the
docstring always said so; the old shopping list was never a mistake).
Now it's functional: the 0.5 web under the pocket is a Ø2.4 hole, the
cab rim-seats dome-down (self-centering; apex depth set by dome
curvature, 0.40 below the rim, so the 2.08-2.10 batch spread doesn't
matter), and the apex at z16.30 is the staff's upper endstone —
endshake 0.30 on glass instead of PLA. Bare (no cab) the staff stops
on the pocket shoulder: degraded but functional. Honest physics: on
the vertical desk stand the staff is loaded radially and the stone
carries little; it earns its keep dial-down, in handling, and as the
visible red jewel. The lower (plate-side) stone is logged for the
next plate revision with the E/P cup tightening. The cab is a posed
component in the STEP (50 total) so the gates see it.

**Coda 5, bench round 2 (Aug 22):** Jon's reprint findings. (1) The
escape wheel's D-bore had ~5 deg of rotational wiggle on its seat —
which is wheel PHASE slop, spent directly out of the gate margins.
The bore is now a press fit (variant press_r on both the round and
the flat); arbors unchanged — wheel-only reprint. (2) "A third of a
millimetre more stone and we're perfect": probe-swept the ramp
schedule — ride 12 / couple 0.85 / floor 13.4 takes the mid-swing
gate from +0.41 to **+0.54 mm** (the ceiling: at ride 13+ the ramp
tail wraps into the next tooth's approach, the rest falls on the
tail, draw inverts, and the tick runs backward — the probe caught
all three). Worst-case bore-slop stretch now leaves +0.46. Combined
with the D-fix killing the phase slop, the bench margin roughly
doubles. Reprint: escape_wheel + pallet_fork only.

**Coda 5, rev 2 (Aug 24) — the bench voted on the endshake tips.**
Jon broke both new features within days: the Ø1.4 reduced top tips
snapped off the minute and third arbors at a touch (a 1.5 mm^2 column
across layer lines — a print-fragile feature I designed), and the
Ø3.5 wheel-to-pinion necks tore in torsion on the minute and third
(the layer-adhesion fuse of every vertical-printed arbor). Fixes:

- Tips DELETED, not beefed: the bridge bearings are now BLIND — a
  shelf at pivot-end + endshake with only a Ø1.2 vent through. The
  plain pivot's flat end face is the up-stop (mean contact radius
  ~0.8, same physics, zero fragile features, simpler arbor). Pivots
  end at 16.1; the bands and the endshake gate moved with them.
- Necks get stepped cone-fillets sized per station against the real
  tooth corridors: minute r3.0-2.3-3.0 (drum tips pass 4.0 away),
  third 2.6 then 2.0 toward its 8-leaf pinion (minute-wheel tips at
  2.5 in the float zone), fourth 1.75 at the bottom (third-wheel
  corridor at 2.0, as always) fattening to 2.6 at its wheel. Waist
  areas up 31-73 percent, and every junction now lands on a step
  instead of a sharp corner — the corner was where both breaks began.
- Lower nose bosses 0.6 -> 0.8 while in there.

**Coda 5, rev 3 (Aug 24): the click, third time, and the pawl-back
lesson.** The saw-tooth rebuild's click still came up short on Jon's
bench — its ~0.95mm engagement kept evaporating into print shrink,
rounded tips and peg slop. Deepening the wedge to r11.3 (1.7mm into
the teeth) jammed the wind at first: below the ramp's convex knee the
tooth wall is near-radial, and a full-depth shallow ramp is
IMPOSSIBLE in a 15-deg pitch (2.3mm of rise at 57 deg needs 14.8 deg
of arc; the pitch has 8.25 free — a knee-scaling attempt folded the
polygon and OCC refused it). The classic answer: the PAWL cams on its
own angled back. The wedge's winding-side flank now runs tip ->
(6.2, 12.0) at ~54 deg off radial; the tooth's knee corner slides
along it and lifts the click regardless of the under-knee wall. Probe
(now measuring BOTH surfaces at the contact — corner-on-flank camming
is governed by whichever is the flank): letdown cliff 8.3 deg in
0.05; winding cams at 53.5; crown drive 59.7/60; reverse hard-stop.
Click is a Class C PETG reprint; ratchet/crown unchanged.

Also answered for the bench: the ratchet and crown wheel are MIRROR
images ("opposing") by necessity — an external mesh presents each
wheel to the other rotated 180 deg, so a pair that look identical
side by side meet ramp-to-cliff and slip (the probe rejected exactly
that pair in coda 4). Assembled view from the bridge: ratchet teeth
hook CCW, crown (slots down) hooks CW.

**Coda 5, rev 4 (Aug 25): the winding stage's assembly paths.** Two
bench failures in one evening, same root class — the pose gates never
walked the ASSEMBLY PATH. (1) The crown stud would not enter its
holes: a stray "+0.35" in the tail radius shipped a O5.34 tail
against the O4.70 bridge bore (10x a press fit) that could not even
pass the wheel's own O5.32 bore. Tail is now bore + press_r with a
lead-in cone. (2) Jon broke the stem tunnel boss forcing the stem in
— and the arithmetic shows the one-print stem was NEVER installable:
O9 pinion on one end, O13.6 crown on the other, a closed O5.4 tunnel
between. There was no legal move; the boss was the fuse. The stem is
now TWO PIECES, the real-keyless-works way: stem + crown with a
D-flat tip slides in from outside; a separate winding_pinion presses
onto the D from inside and butts the tunnel's inner face as its
thrust shoulder; the C-clip is unchanged. New gates walk the paths:
the stud's widest tail section must pass the wheel bore and press the
bridge bore within a sane band; every stem section inboard of the
tunnel must pass O5.4. Kit gains winding_pinion (45 parts); reprint =
crown_stud, stem_and_crown, winding_pinion, and the bridge Jon broke.

**Coda 5, rev 5 (Aug 26): bridge-landing bench round.** Four at once.
(1) Wheels still rubbed the bridge: the shoulder-stop margin was
face-gap 0.45 minus endshake 0.35 = 0.10 — one short-printed pivot
wide. Fixed on the ARBOR side so the printed bridge survives: top
pivots +0.15 (end 16.25), endshake 0.20, shelf formula re-anchored so
the shelves land where the printed bridge already has them; margin
0.25. (2) The stem must go into the bridge BEFORE the bridge mounts
(the pinion press needs finger room under the web) — now Stage 4 step
1. (3) The click's peg holes scar (the pocket prints face-down):
holes r1.35 + chamfered mouths for future prints, and a bench note —
twist a Ø2.5 bit through by hand on the current one. (4) The M2x6's
forming taper exited the under-web boss flush and the last threads
stripped: the click grew a 0.5 screw boss that keeps the tip captive.
Reprints: four train arbors + click; the bridge is UNCHANGED at the
bearings by construction.

**Coda 5, rev 8 (Sep 30): the click boss twists off.** Driving the
click's M2x6 sheared the r2.4 under-web cylinder clean off the web
(Jon's bench: "couldn't hold up to the rotational forces created by
the screw"). What the section measurement shows: the two click-peg
holes sit 1.6 and 2.1 from the screw axis, so the stub's root met the
web over 8.3 mm^2 — two crescents between three holes — where a full
annulus would have been 15.5. The boss is now a cone, root r5.5 on
the web tapering to r3.0 at the tip: the root ring lands on unbroken
web outside the peg holes (81.9 mm^2, and ~22x the first polar moment
about the screw axis), the tip keeps 2.1 of wall around the pilot,
and the peg holes become blind under it. The space was free all
along: nothing but the screw itself occupies r9 of that axis above
the drum top. A new gate measures the root section on both sides of
the web interface. Lesson for the fastener gates: "the screw threads
3.5 mm" was asserted; "the thing it threads into can carry the
driving torque" was not. Reprint: **bridge_wave** only — click,
screw and pegs are unchanged.

The section drawing that checked the cone also caught the gate
itself lying. Rev 5 raised the click's screw seat 0.5 (the captive-tip
boss) but the posed screw in the STEP stayed at z17.65, head buried
in that boss — so the thread gate measured 3.67 mm for a screw that
really has 3.17: 2.55 full-circle in the under-web boss plus 0.62
equivalent in a web whose pilot the peg holes break open. Pose fixed
(seat z18.15); the click's gate is set to 3.0 and says why. The
stack caps it — 6.0 of shank, 2.1 through the click, 1.3 of pierced
web — and the bridge cannot add thread. **Open item:** a click
revision with pegs clear of the pilot would close the web around the
screw (+0.7) and is the way to buy margin if this joint ever strips.

## Cost recorded honestly

Reprint: **escape_wheel** ×3 (mirrored tooth, flat tip) and
**pallet_fork** ×3 (envelope-built stones, third print — coda 2's
reasons plus coda 3's), **bay_strap** (feet moved, bosses),
**mainplate** (strap + platform pilots), **bridge_wave** (click boss).
The plate and bridge were already queued for the 0.11-fit wave, so
this rides along. Wheel and train untouched. Open items for the
balance-driven bench: catch retrograde, ~52 deg draw on the tucked
nose face.

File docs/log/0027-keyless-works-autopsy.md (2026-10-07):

# 0027 — The keyless works: an autopsy

Oct 1, 2026. The train finally spins on a touch of the drum — the
endshake and tooth-form work of log 0026 landed. Jon moved on to
winding and reported that the crown and stem do nothing at all: the
crown wheel sits loose on its stud and drifts out of the ratchet, and
even held down by hand the stem's pinion "just slides underneath it".
His question was whether this form of winding can work on a printed
movement or whether we bail.

This entry is the measurement, not the fix. Nothing in the winding
train was changed; one bench tool was added.

## What was measured

Three faults, each independent, each enough on its own.

**1. The ratchet and crown wheel cannot mesh over the crown wheel's
full height.** Both are 24-tooth saw wheels, r13 tips, at centre
distance 24. Sectioned in plan and tried at every phase:

| height | result |
|---|---|
| z16.05–17.15 (through the underside slots) | nests — 28 of 30 ratchet phases have a free crown phase |
| z17.15–17.65 (above the slot roof) | never nests; least overlap 0.35 mm² at the best phase |

The pair only interleaves where the pinion slots happen to carve
clearance out of the crown wheel's teeth. The top 0.5 mm is the full
saw profile, and that needs the wheels more than 0.5 mm further apart
(overlap is still 0.05 mm² at 24.5, zero by 25.0). On the bench the
crown wheel gets shoved outward by that slab — which is exactly "loses
engagement with the ratchet". The gate that should have caught it,
`_mesh_pair`, tolerates 0.5 mm³ of overlap at one pose; this collision
is 0.30 mm³ there and passed.

A second finding from the same trace: the crown wheel's cliffs face
counter-clockwise, and it winds by turning clockwise. So it pushes the
ratchet with the sloped backs of its teeth, not cliff-to-cliff as the
comments claim. The drive still transmits; it also pushes the wheels
apart harder than it should.

**2. The crown wheel's axle is barely attached.** The stud is a 0.03
radial press over 0.91 mm of full diameter (1.31 with the lead-in) in
a web 1.3 thick. It has to resist the ratchet mesh's side load 0.85
above the pocket floor and whatever lift the pinion produces. It
cannot; fault 1 supplies the side load.

**3. The stem pinion never properly enters the crown wheel.** Stem
axis z12.8, pinion tip radius 4.13 (pitch radius 3.5 plus a 0.63
semicircular nose), wheel underside z16.05:

| | reach into the wheel |
|---|---|
| leaf at top dead centre | 0.88 mm |
| half a pitch later, at hand-over | 0.47 mm for both leaves |

The pinion's pitch line sits 0.25 above the land bottoms, so all of
that engagement is rounded nose. Tips on a 4.13 circle are 3.71 apart;
the slots are 3.14 apart at r12. Drawn at hand-over, the two leaves
sit under the lands either side of a slot, not in one: the next leaf
arrives bearing upward on a land's underside. With fault 2, upward is
free. That is "slides underneath".

## The number nobody has

Sizing a replacement turned up something bigger than geometry. The
mainspring as drawn — PETG, 2.2 x 6.0 strip, 425 long — works out to
about 160 N.mm per turn of wind (E taken as 2.0 GPa). That is 13 N on
one ratchet tooth per turn, 26 N at two. A module-1 PLA tooth 1.6 wide
is near its limit around 20 N. So are the click's wedge, the arbor's
hollow square (0.7 wall around the key socket) and the stem's Ø3
D-tip. `SPRING_C` has carried "TORQUE FLAG: bench-validate" since the
port; it has never been validated because the movement has never been
wound.

A crown-and-stem train that fits the present bridge window and stem
height can be made to mesh correctly, but only with a face 1.2–2 mm
wide at module ~0.85. By the same tooth-stress estimate that is fine
at a fraction of a turn of this spring and marginal by one. Sized for
the spring as drawn it would want something like module 1.25 teeth, a
wider window in the web, and taller wheels standing proud of the
bridge — a bridge change, sketched but not yet simulated. Which of
those is right depends on how much torque the train actually needs,
and that is a bench number.

## What was built

`ratchet_knob_c` / `tools/export_bench_tools.py` →
`exports/k1/print/bench/winding_knob.stl`: the ratchet with a fluted
finger knob on top. Below z17.65 it is the ratchet, section for
section; above, it clears the click by 0.70, the crown wheel by 0.60
and the bridge by 1.66. It winds the barrel directly through the click
that is already there, and it is the instrument for the torque number.

Three tests now record the faults as strict expected failures
(`test_keyless_*`). The redesign is done when they pass.

## What was learned about the gates

- A volume tolerance on one pose is not a nesting check. Two toothed
  wheels need a free phase at every height, in section.
- "Overlaps when the wheel is turned half a slot" proved the pinion
  touches the wheel, not that it drives it. The hand-over depth is the
  number.
- None of the winding gates ever asked what force the teeth carry.

## Bench round 1 (Oct 2) — and what it changed

Jon printed the knob, held the escape wheel, and wound.

| what he saw | what the model says |
|---|---|
| "significant tension at about half a revolution" | ~79 N.mm, 6.6 N on one ratchet tooth |
| "not quite one full revolution before it gets very very tight" | 425 mm of 2.2 strip packs solid on the hub at 5.39 coils; it is printed at 4.25. **1.14 turns** and it is a solid puck. The "2.8 usable turns" in `SPRING_C` was never true |
| the arbor's square "slips out of" the ratchet, "even as I am pressing down quite firmly" | the square was 1.6 tall, hollowed by a 2.6 key socket to a 0.7 wall, in a bore with 0.15 a side of play |
| "the click does not hold at all" | two faults. In its pocket the click could lift 0.64 before the arm met the wall; a tooth needs 1.70. And the ratchet pushed the arm INTO its anchor (direction cosine +0.97): a 1.3-wide, 19-long kinked PETG strut in compression |
| released at half a turn, "the whole gear train moves, and the escape wheel turns very rapidly for about 15 seconds" | the first time this movement has run on its own spring |
| winds counter-clockwise | as derived |

Three parts changed. The bridge did not.

**Barrel arbor.** Solid 4.0 square, 3.4 tall (z16.0–19.4). 4.0 is the
largest square whose diagonal passes the bridge's web bearing.

**Ratchet.** 3.45 thick: the lower 1.6 in the pocket as before, 1.8
proud of the bridge. Bore 4.15 with a chamfered mouth (it prints on
the bed; an elephant-footed mouth is a taper that helps the square
climb). The knob grows from the new top.

**Click.** A pull-pawl, working in the open air above the bridge top.
The mounting is untouched — same block pocket, same two pegs, same
screw into the cone boss — but the block now carries a plate that
seats on the bridge's top surface, and from the plate a 0.8 x 3.0
flexure neck leads to a curved pawl that wraps a sixth of the way
round the ratchet to a hook. The pivot is on the far side of the
contact and 18 deg inside the tangent there, so the tooth PULLS the
pawl (tension cosine 0.98) and the pull has a 2.5 mm lever swinging
the hook into the tooth with no help from friction. The hook's lock
face leans 8.3 deg like the ratchet's cliff, so they meet flat. Lift
to pass a tooth: 7.2 deg, 1.76 mm, 1.7% strain in the neck; nothing
above the bridge is in its way. Printed 0.08 fat on both parts the
hook seats 0.9 deg proud and everything else holds. `tools/probe_click`
runs this on the built solids and `test_revc_winding_is_one_way` is
now that contract.

Not changed, and why: the mainspring. It is far stiffer than the bare
train needs and it has one turn in it, not three — but what the
escapement needs is the number that sizes it, and the balance is not
in yet. Until it is: wind 18 teeth at most.

The crown-and-stem redesign waits on the same number.

## Bench round 2 (Oct 2) — the balance goes in, almost

With the new arbor, knob and click: the click holds. Jon went to
install the balance and found three more things.

**The timing screws never fitted.** Six M3x8 steel screws through the
rim at r23 were the rate weights. A socket-head M3x8 stands 3.0 proud
of one face of a 3.4 rim and 4.6 of the other. Swept round the balance
axis, that radius has the hairspring's outer coil 0.7 above the rim
and the pallet strap 0.5 below. The screws were hardware in a
docstring; they were never posed in the assembly, so no gate ever met
them. The weights are now 16 M3 nuts pressed flush into hex pockets at
r22.5 — measured from the solids, that lands the balance at about 5500
g.mm^2, the inertia the six screws were meant to give (the bare wheel
is 2200). They are posed parts now, with a gate on their path. Trim is
by count, in opposite pairs.

**The staff would not enter the wheel.** Jon's rod is brass, O2.96.
The wheel's bore was O2.90 where the roller and collet use O2.94; it
now uses the same press as they do.

**The cabochon would not stay in its pocket.** The garnet endstone
pressed into a O3.95 hole from above; on Jon's print it was loose. The
cock's blind cup now has a flat printed floor at z16.3 that does the
same job — the same 0.30 of endshake over a 13.8 staff — and, with the
cock printed arm-down, that floor is a clean top-of-layer surface. The
stone was a nice idea that depended on a press fit nobody had tested.

## Before printing the balance: the fork end (Oct 2)

Jon, looking at the roller and the fork's end before committing hours
of plastic: "I'm just not entirely certain that that little three
prong area under the fork is going to allow that thing to control it
well." He was right, and the existing gate could not have told him.

Run as a pass, from the solids (`tools/probe_fork`):

- **The pin could not get in.** The fork's end was two straight prongs
  reaching 0.7 past the pin's centre, the pin O2.5 on a 5.5 orbit, the
  fork swinging +-6.5 deg at 13.9 from its pivot — a sideways throw of
  1.57 for a pin of radius 1.25. With the fork parked at its banking
  the returning pin met the flat END of the near prong at 42.5 deg
  before centre. A push on that face turns the fork INTO its banking.
  Dead stop.
- **It could not get out either.** Released from centre, the pin met
  the same prong again 10 deg after it.
- **The guard finger guarded nothing.** It stopped 0.3 short of the
  safety roller measured AT CENTRE, so its tip never came within 0.3
  of the roller at any fork angle: a knock could carry the parked fork
  clean across at 115 of 145 balance phases.

The old test posed fork and roller in eleven static states. For the
phases near the pass it paired the fork with the banking AWAY from the
pin ("after exit, draw holds the away-side bank"). The fork follows
the pin; that pairing never occurs, and it is the only one that is
clear.

Flaring the horns alone does not fix it. With a O2.5 pin the approach
sweeps through x' 13.6 in the fork's frame — inside the place the
notch wall has to stand to hold the pin at centre (13.91). The pin is
too fat for the throw. So three changes, together:

| | was | now |
|---|---|---|
| impulse pin | O2.5 | O1.8 |
| notch | 3.1 wide, parallel walls to the prong ends | 2.2 wide; walls stop 0.36 short of the pin's centre-line position, then horns flare at 60 deg |
| guard | square finger, 3.5 from the balance axis | pointed dart, tip centre 3.16 from the axis, r0.3 |

As drawn the pin first moves the fork 12.5 deg before centre and the
fork is home on the far side 13 deg after: 25.5 deg of lift, and the
pin leaves clean. Printed 0.05 thin to 0.10 fat it still passes
(23.5 to 29.5 deg of lift). A knock moves the parked fork no further
than +3.7 deg (+2.8 thin) before the dart meets the safety roller or a
horn meets the pin. One honest limit: the escape wheel begins to
advance after about 1.25 deg of fork travel, so a hard knock can still
trip a tooth before the dart lands — the fork then leans on the roller
until the notch comes round. It cannot cross.

Reprint: pallet_fork, roller. `test_revc_roller_passes_through_the_fork`
is the contract now.

## Hairspring stiffness and the pivot-friction budget (Oct 2)

Jon, twisting the printed hairspring on the bench: "very very soft —
a 30-40 degree arc where even the friction of sitting on smooth
plastic stops it returning." From the drawing: 1307 mm of 0.45 x 1.75
PETG, k = 0.020 N.mm per radian (E taken as 2.0 GPa) — 0.012 N.mm at
35 deg, 0.064 at 180. The spring's own weight dragging on a table at
r16 is about 0.06 N.mm. So the observation is the design, not a
defect: a hairspring never has to beat table friction, only the
staff's ends.

Which is the real number to worry about. The balance is 13.9 g with
its sixteen nuts, on O3 ends:

| position | friction torque at the staff (mu 0.15-0.3) | compare: spring at 100 / 180 deg |
|---|---|---|
| lying flat, rounded tip, contact ~r0.3 | 0.006-0.012 | 0.036 / 0.064 |
| lying flat, flat-cut tip | 0.02-0.04 | |
| standing on the desk stand (journal on O3) | 0.03-0.06 | |

Impulse from the train at 12 teeth of wind is ~0.011 mJ per beat; the
energy stored at 180 deg is 0.10 mJ. Lying flat with a rounded tip the
loss per half-swing is ~0.025 mJ at 180 — the balance should run at
100-200 deg. Standing up the journal loss is 0.13-0.25 mJ per
half-swing: more than the balance holds. It will not sustain.

First tick is therefore a lying-flat test. Standing up needs a lighter
balance, a stiffer spring with less inertia, or pivots far smaller
than O3 — the rev D conversation. Expected beat with all sixteen nuts:
~0.31 Hz (3.3 s per full swing), not the 0.53 the docstrings carried;
the balance alone, no nuts, would be ~0.48. The nuts are the trim.

## The escapement had no lock (Oct 2–3)

Jon, with a little wind on the barrel and the balance out: "the pallet
fork is too loose. It freely flops back and forth, letting the energy
out of the system." Right diagnosis, wrong suspect. A fork that flops
under wind has nothing holding it: the escapement has no lock and no
draw.

**Measured.** With the fork parked at its banking the solver had
shrunk the stone's locking face to **0.04 mm** — silently: the
coda-3 lock gate checked the contact's azimuth and a "draw torque"
whose sign rule was wrong, and never the lock depth or what happens
when the fork moves. Run as kinematics, moving the fork off its
banking moved the wheel FORWARD from the first tenth of a degree. The
tooth rested on a ramp, so the wheel pushed the fork off its pin, the
fork crossed, the next tooth did the same from the other side. That
is the flop.

**Why the solver gave up the lock.** A locking face with draw leans
UPSTREAM from the tooth's rest point: lifting the stone then makes the
tooth back up along the face, so the wheel recoils and its torque
holds the fork on the pin. Such a face can only exist in the space
behind the tooth's tip — and the coda-3 tooth leaned FORWARD, its body
ahead of the tip, with a stone face behind the tip running straight
into the body of the next approaching tooth. (The first two hours of
this fix went the other way, with the tooth leaning back but the face
chosen downstream; that gave a face but no recoil. The kinematics are
in `lever_layout_c`'s draw comment now, derived rather than guessed.)

**Changed, together:**

| | was | now |
|---|---|---|
| escape tooth | leaning forward, face falling ahead of the tip | leaning BACK: tip foremost, leading face receding 28 deg behind it, back at 42 deg; `tooth_profile_pts` is the one source for the wheel and the solver |
| stone locking face | through the tip's centre, 0.45 reserve (solved to 0.04) | through the tip flat's downstream corner, 0.60 reserve, 15 deg of draw with the inner end upstream |
| clearance rule | an analytic "hook-back" envelope that assumed the old tooth | a point-in-tooth test on the real profile, 0.10 margin |
| impulse ramp | ride 12 deg | ride 10 (at 10.5+ the other stone's lifted ramp tail reached the tip circle and the wheel rested on it) |
| the gate | contact azimuth + a torque heuristic | `probe_escapement.report`: rest on the right stone, recoil, unlock angle, half-pitch advance, drop, gate, windows — sharp AND r0.1-rounded tips |

As drawn: the wheel rests tip-on-face on both stones; moving the fork
1 deg off its banking backs the wheel up 0.22 deg; the tip stays on
the face for 3.3 deg of fork travel, then the ramp takes it and a
half-swing advances exactly half a pitch with 4.6 / 3.4 deg of free
drop. With the tooth corners rounded r0.1: unlock after 1.9 deg, recoil
0.20, drop 5.8 / 2.6. The old "step in a rapid buzz without a balance"
in the assembly guide was the fault described as a feature; the gate
now says the wheel must lock and stay.

Reprint: escape_wheel and pallet_fork — the same pair as this
morning's horn fix, so nothing extra if those are not printed yet.

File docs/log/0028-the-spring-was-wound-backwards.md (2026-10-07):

# 0028 — The spring was wound backwards

Oct 6, 2026. Jon could not feel the mainspring holding energy, opened
the drum, and found the spring broken: the inner C-loop snapped off
where the spiral left it (IMG_4063). He asked whether the reprint was
the moment to fix the spring properly. It was — and his photo showed
the first fault before the fracture did.

## Three faults, one spring

**1. The wrong hand.** Look into the open drum from the cover side
(bridge view). The broken spring's strip runs outward
*counter-clockwise* from the arbor. The arbor winds *counter-clockwise*
(the click blocks clockwise; coda 4 derived it from the train's
chirality, and Jon's bench confirmed the click holds that way). Turn
the inner end of a spiral the way its coils run and you *unwind* it:
the same strip has to span fewer degrees, so it moves out, not in.
Every counter-clockwise wind pressed the coils out against the drum
wall. That is why it went "heavy at half a turn, solid under one" — the
packing arithmetic of log 0027 predicted 1.14 turns to solid the
*right* way round, so the number agreed by accident and hid this.

`mainspring_c()` drew that hand (angle rising with radius), the guide
said "spiral as printed", and a flat spiral turned over is its own
mirror image. Nobody said which face up because nobody had checked the
hand against the winding direction.

**2. A notch at the root.** The inner end was a C-loop at r6.6 with
the spiral leaving it tangentially. Where the strip's inner edge parts
from the loop the two faces meet at a near-zero angle: a crack starter
at exactly the point carrying the full torque. The fracture is there.

**3. Too much strain.** A spiral strip under a pure moment strains
uniformly, ε = π · turns · t / L. At 2.2 thick, 425 long, 1.14 turns
to solid: 1.85% — and at the hub the first coil, printed at r6.9 and
wound onto r5.5, sees 4%. PETG yields around 2.5%. Wound the right
way, this strip would have broken on its own schedule.

## The spring now

`SPRING_C` / `mainspring_c(t)` / `mainspring_layout(t)` in
`calibers/k1/revc_parts.py`:

- **Hand:** outward CLOCKWISE in bridge view, so a counter-clockwise
  arbor tightens it. Gate: `test_revc_mainspring_is_the_hand_the_click_winds`
  checks material along the designed centreline on the built solid and
  that its angle falls as the radius grows.
- **Which way up:** the blind hole in the outer tab's top face. Hole
  toward the cover; print hole side up.
- **Inner end:** a solid ring (r5.65–8.5) over the arbor's r5.5 hub with
  a keyway for the hub's existing 2.4 mm rib — the arbor is unchanged.
  The strip grows out of the ring through a root 1.6 t thick that
  tapers to t over 115°, its inner face peeling off the ring on a
  smooth curve and its back rising out of the ring on a ramp. No loop,
  no notch; the ring takes the rib's push in bearing.
- **Outer end:** a 5 mm tab from inside the last coil to 0.4 off the
  wall, its counter-clockwise face 0.3 off the drum rib's clockwise
  face, which takes the tangential pull — and a Ø2.8 blind hole in its
  top for a **Ø2.5 pin on the underside of the drum cover**, which takes
  the inward pull. See "Jon's second finding" below for why the pin
  exists. The last coil stays inside r24.6 so the top millimetre of the
  strip clears the three cover lugs at r24.9 — the old spring's r26.3
  outer coil did not, and sat pushed in by them.
- **Sizing rule:** the coils pack solid on the ring — the only stop a
  going barrel has — at or under 1.5% strain (30 MPa). So the
  instruction is "wind until it stops", and it cannot be overwound.
  For the kit's 1.7 strip: pitch 3.62, 4.0 printed coils, 414 mm,
  solid at 1.14 turns (27 ratchet teeth), 75 N·mm per turn, 85 N·mm at
  solid, 1.48%.

## The torque question is still open

The number that sizes this spring is what the train needs at the drum
with the balance running, and we do not have it. Two estimates bracket
it badly: the bare train ran on under half a turn of the old spring
(< 80 N·mm), while an energy budget for the balance (pivot friction
~0.003–0.012 N·mm, lever efficiency ~0.35, 418:1 from escape wheel to
drum, ~0.5 through four printed meshes) lands anywhere from 100 to
700 N·mm. If the high end is real, no PETG strip in this drum delivers
it for more than a fraction of a turn: a spiral strip's torque is
bounded by σ·h·t²/6, and the turns available by the difference between
coils packed on the ring and coils as printed, which this drum caps
near 1.5 regardless of length.

So the spring is a ladder: `MAINSPRING_LADDER = (1.4, 1.7, 2.0)`.
Same ring, keyway, root and tab; only the strip changes.

| strip | turns to solid | teeth | N·mm/turn | N·mm at solid | strain |
|---|---|---|---|---|---|
| 1.4 | 1.39 | 33 | 35 | 49 | 1.26% |
| 1.7 (kit) | 1.14 | 27 | 75 | 85 | 1.48% |
| 2.0 | 0.97 | **stop at 20** | 141 | 136 (120 at 20) | 1.70% |

Jon prints all three, starts on 1.7, and reports which run and for how
long from solid. If 2.0 is the only one that runs, rev D needs a
different answer — a smaller drum ratio than 6 h/rev (more turns per
hour of running), or a steel strip, which stores ~1000× the energy per
volume and is the one place metal buys the most.

## Jon's second finding: why the tab popped off

Jon had in fact tried the right hand first. His words: "when I put it
the other direction, it would just pop out of the nub that was supposed
to hold it in place, so you couldn't build torque." So he turned it
over, and the wrong hand *held* — because a spring wound the wrong way
expands, pressing its outer end out against the wall and onto the rib.

The right hand does the opposite, and it is not a detail. A relaxed
printed spiral, wound, draws its coils in toward the ring; the outer
coil lifts off the wall and the strip leaves the anchor on a chord
toward the pack, pulling the anchor *inward* at roughly 0.6 of the
strip tension (about 2 N on the kit spring). A real mainspring never
sees that pull: its free shape is reverse-curved so the outer coils
press outward on the barrel wall even fully wound, and a plain hook
suffices. Ours has no such pre-stress, and a drum wall has no surface
that faces outward: the wall faces in, the rib faces in and sideways.
No hook, pocket or dovetail on the tab can be retained by them against
an inward pull — I drew one (a pocket over the rib) before working
that out. The only outward-facing surfaces in the barrel are the
arbor's, and the floor and cover's.

So the anchor is vertical: the **drum cover carries a Ø2.5 pin, 2.5
long, that drops into a Ø2.8 blind hole in the tab** (`cover_pin_xy()`,
`SPRING_C["pin_*"]`). The rib still takes the tangential load on the
tab's counter-clockwise face, 0.3 away; the pin takes the inward pull
(2–4 N in shear on a PLA pin — nothing) and, as a side effect, stops
the cover rotating. The cover's lift is limited to under a millimetre
by the bridge web above it, so the pin stays engaged. The cover
reprints (Class B, pin up); the drum does not. Gate:
`test_revc_mainspring_lives_in_the_drum` now pulls the spring 0.6 mm
inward and 1° each way and demands a collision each time.

## Bench consequences

- Discard the 2.2 spring. The arbor and drum stay; the **cover reprints**
  (it carries the spring's anchor pin).
- `exports/k1/print/mainspring.stl` is the 1.7; `bench/mainspring_t1.4.stl`
  and `bench/mainspring_t2.0.stl` are the rungs; the bench README has
  the table and the stop for each.
- Assembly guide Stage 1 rewritten around the ring, the rib, the hole
  and the cover pin; the Stage 1 gate names the direction that should
  resist.
  The "18 teeth" rule in Stage 5 and the bench README is replaced by
  "wind until it goes solid" (and 20 teeth for the 2.0 strip).
- The STEP now poses the spring with the arbor's rib in its keyway.
- Gates: `test_revc_mainspring_is_the_hand_the_click_winds`,
  `test_revc_mainspring_lives_in_the_drum[t]` (no overlap with drum,
  cover or keyed arbor; rib fits only the keyway; tab reaches the rib;
  coils print ≥ 0.8 apart), `test_revc_mainspring_cannot_be_overwound[t]`,
  and the spring joined the z-band table.

## What this says about the earlier bench rounds

Not what I first wrote. A wrong-hand spring still releases the drum
the right way: whatever the coils do, a counter-clockwise twist of the
inner end relative to the outer unwinds as a counter-clockwise drum.
So the half-turn that "ran the bare train for 15 seconds" ran it
forward, and the fork-flop video of log 0027 was taken with the wheel
turning the right way. What was contaminated is the torque: a spiral
jammed outward against the wall delivers its energy through wall
friction, on a curve nobody can predict, with its root at the notch
carrying all of it. The lock redesign stands on its own measurement
(the solver had shrunk the locking face to 0.04 mm); what the bench
saw it under is anyone's guess. The first clean torque the escapement
will ever see is this spring's.

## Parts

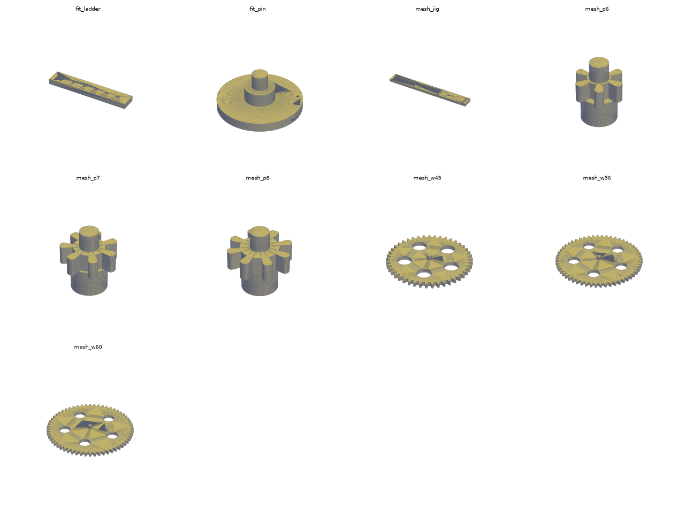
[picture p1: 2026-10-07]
exports/k1/print/coupons/preview_all_parts.png

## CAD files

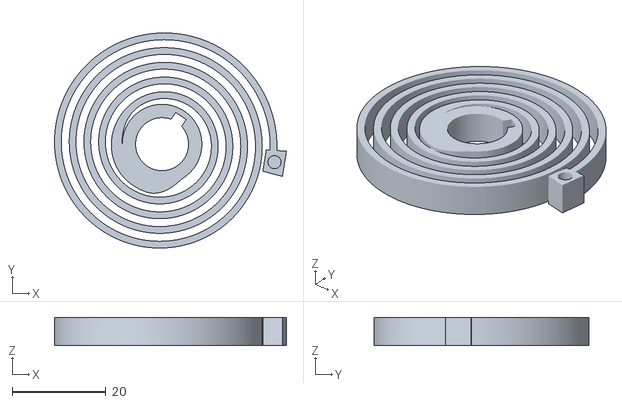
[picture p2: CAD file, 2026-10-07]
exports/k1/print/bench/mainspring_t1.4.stl
49.5 x 45.9 x 6.00

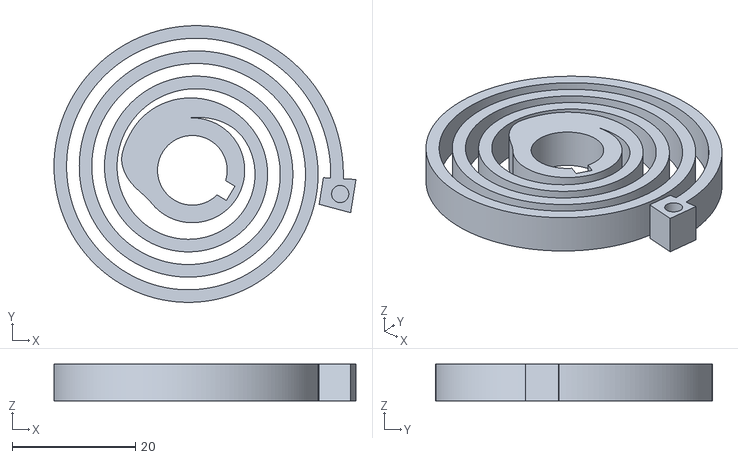
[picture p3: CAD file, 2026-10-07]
exports/k1/print/bench/mainspring_t2.0.stl
49.0 x 44.9 x 6.00

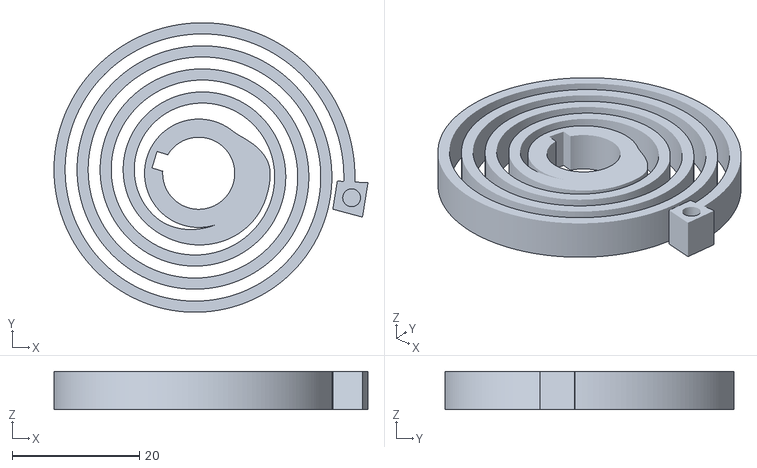
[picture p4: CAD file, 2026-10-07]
exports/k1/print/mainspring.stl
49.3 x 45.4 x 6.00

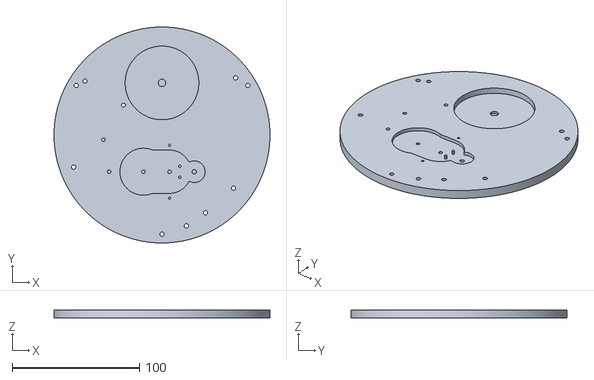
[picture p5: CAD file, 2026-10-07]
exports/k1/print/mainplate.stl
170.0 x 169.9 x 6.50

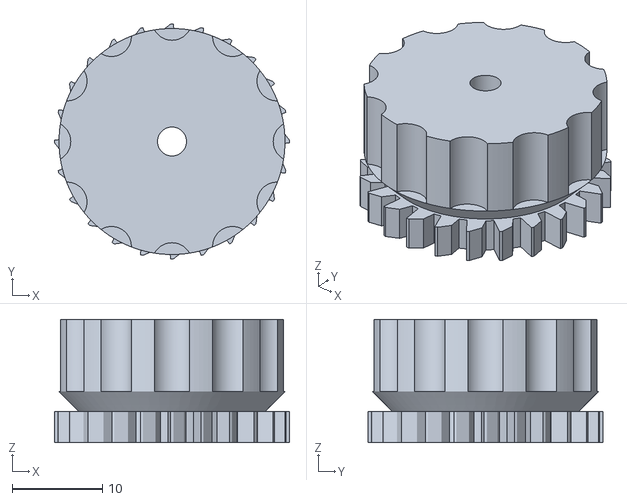
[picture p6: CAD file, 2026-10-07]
exports/k1/print/bench/winding_knob.stl
26.0 x 26.0 x 13.7

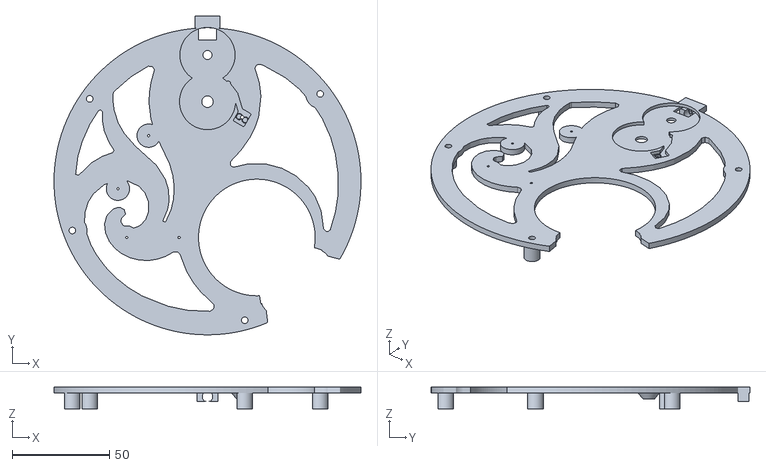
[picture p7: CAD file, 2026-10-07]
exports/k1/print/bridge_wave.stl
158.0 x 164.0 x 11.2

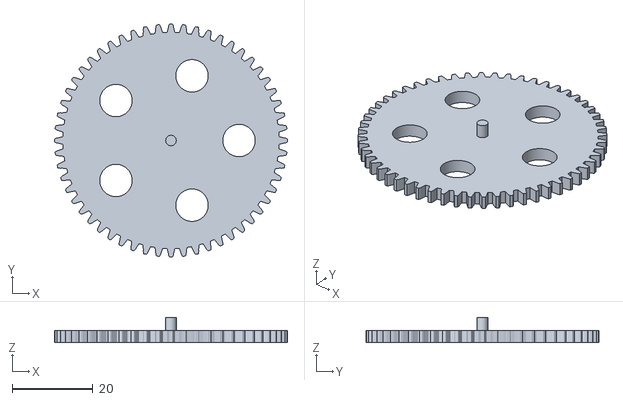
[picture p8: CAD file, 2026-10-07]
exports/k1/print/coupons/mesh_w56.stl
57.6 x 57.6 x 6.20

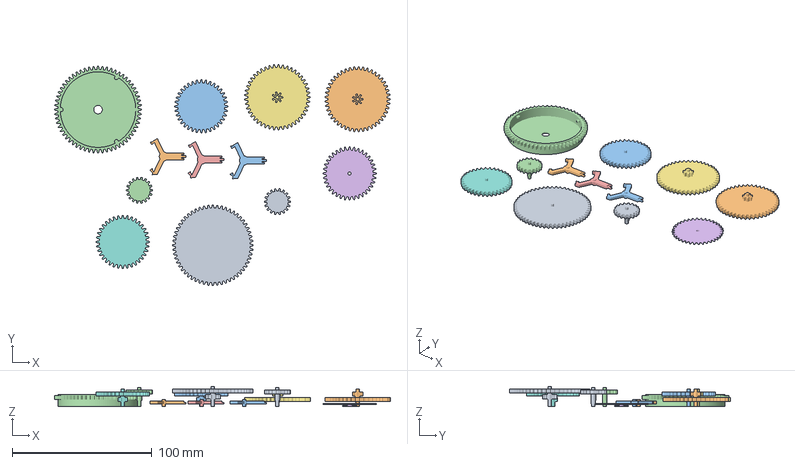
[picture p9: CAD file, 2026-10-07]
exports/k1/print/plates/k1-arbors-escapement.3mf
240.2 x 158.1 x 14.6 mm
minute_arbor.stl
third_arbor.stl x 2
fourth_arbor.stl x 2
escape_arbor.stl x 2
pallet_fork.stl x 3
motion_arbor.stl
drum.stl

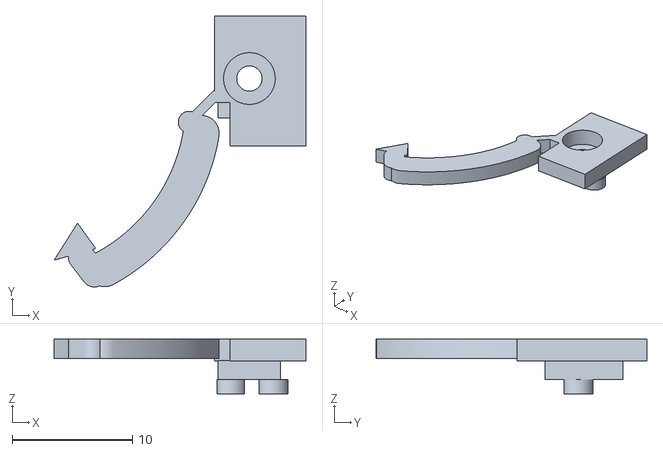
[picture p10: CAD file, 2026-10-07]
exports/k1/print/click.stl
20.9 x 22.5 x 4.55

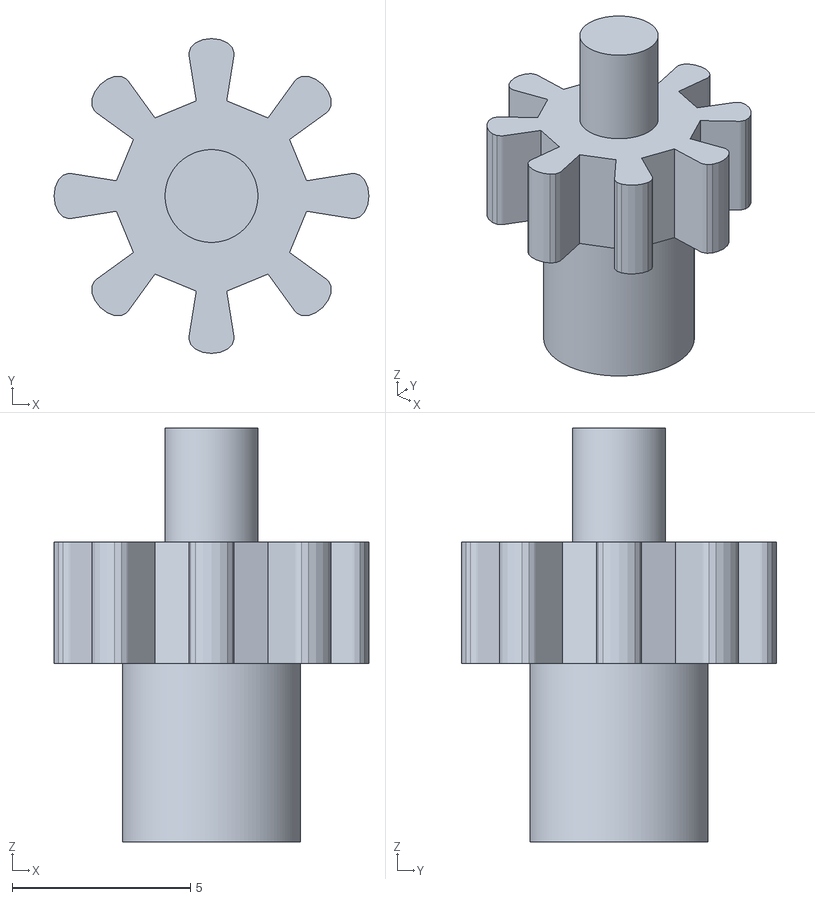
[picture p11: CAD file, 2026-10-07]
exports/k1/print/coupons/mesh_p8.stl
8.82 x 8.82 x 11.6

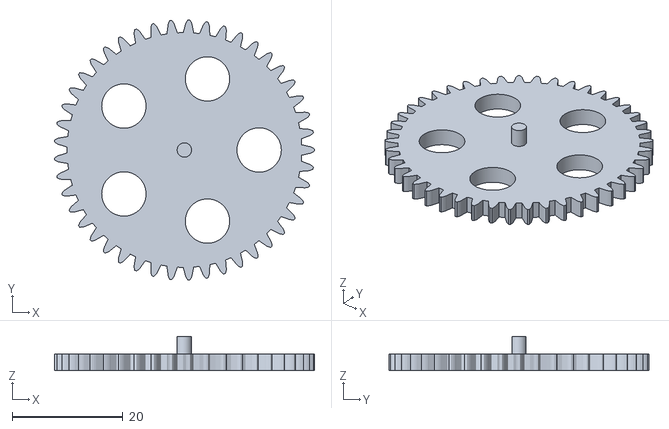
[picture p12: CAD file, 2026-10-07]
exports/k1/print/coupons/mesh_w45.stl
47.0 x 47.0 x 6.20

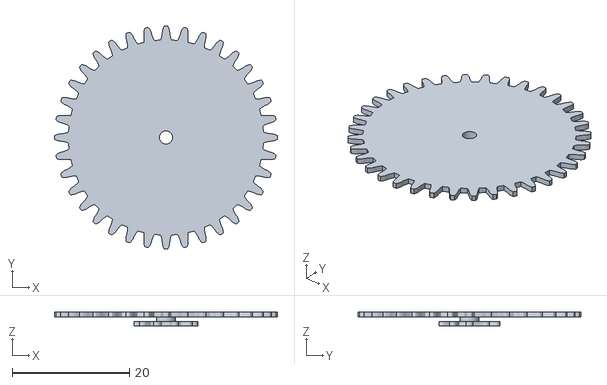
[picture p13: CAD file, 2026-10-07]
exports/k1/print/motion_arbor.stl
38.0 x 38.0 x 2.40

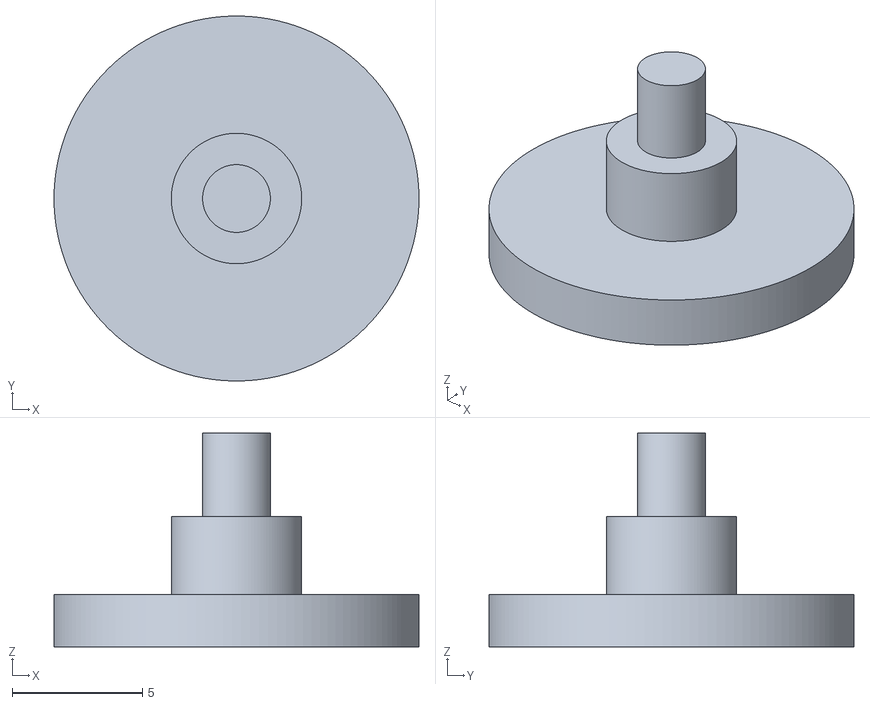
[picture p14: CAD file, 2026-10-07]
exports/k1/print/coupons/fit_pin.stl
14.0 x 14.0 x 8.20

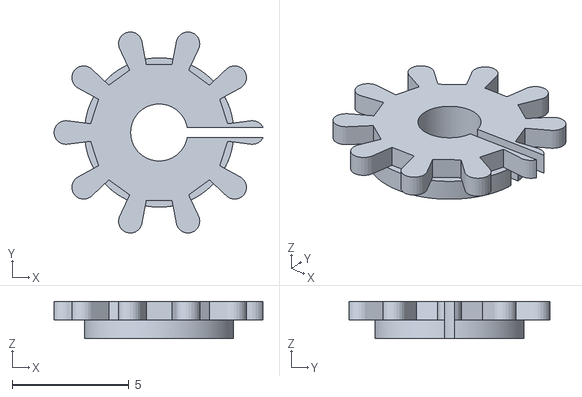
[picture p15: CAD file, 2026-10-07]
exports/k1/print/transfer_pinion.stl
8.96 x 8.62 x 1.60

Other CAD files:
exports/k1/print/coupons/fit_ladder.stl
exports/k1/print/pallet_fork.stl
exports/k1/print/coupons/mesh_p6.stl
exports/k1/print/escape_wheel.stl
exports/k1/print/balance_cock.stl
exports/k1/print/balance_wheel.stl
exports/k1/print/barrel_arbor.stl
exports/k1/print/bay_strap.stl
exports/k1/print/cannon.stl
exports/k1/print/coupons/mesh_jig.stl
exports/k1/print/coupons/mesh_p7.stl
exports/k1/print/coupons/mesh_w60.stl
exports/k1/print/crown_stud.stl
exports/k1/print/crown_wheel.stl
exports/k1/print/dial_sheet.stl
exports/k1/print/drum.stl
exports/k1/print/drum_cover.stl
exports/k1/print/escape_arbor.stl
exports/k1/print/fourth_arbor.stl
exports/k1/print/hairspring.stl
exports/k1/print/hour_wheel.stl
exports/k1/print/minute_arbor.stl
exports/k1/print/moon_disc.stl
exports/k1/print/moon_w1.stl
exports/k1/print/moon_w2.stl
exports/k1/print/ratchet.stl
exports/k1/print/roller.stl
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

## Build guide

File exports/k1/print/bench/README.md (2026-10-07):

# Caliber K1 — bench tools (generated by tools/export_bench_tools.py)

Not movement parts. Not in the kit MANIFEST.

## winding_knob.stl

The ratchet with a finger knob grown on top: wind the barrel directly.

- **Print:** PLA, Class B settings (0.12 layers, 4 walls, 100% infill),
  **ratchet teeth DOWN on the plate**, no supports (the flare is 45 deg).
- **It needs the log-0027 parts with it:** the barrel arbor with the
  solid 3.4 mm square, and the pull-pawl click. An older knob on the
  older hollow square slips off under load — that was bench round 1.
- **Fit:** leave the crown wheel and its stud out — as drawn they
  cannot mesh with the ratchet and only add drag. The stem can stay in
  the bridge as a dummy. Press the knob onto the arbor square, teeth
  in the pocket. The fit is snug on purpose: press it fully home.
- **Wind:** turn the knob COUNTER-clockwise looking down at the bridge.
  The click ticks over each tooth and holds when you let go. With a
  log-0028 spring, wind until it goes solid and stop there (the table
  below says how many teeth that is for each strip) — it is sized so
  that solid is inside the PETG's safe strain. Never force past solid.
- **Let down:** hold the knob and wind it a hair further to take the
  load off the hook, push the click's hooked end outward with a
  fingernail, and let the knob turn back slowly in your fingers.
- **Remove:** a O3 pin down the knob's centre hole pushes the arbor
  free if the square grips.

## mainspring_t1.4.stl, mainspring_t2.0.stl — the strip ladder (log 0028)

The torque the train needs with the balance running is still
unmeasured, so the mainspring comes in three strip thicknesses; the
kit's mainspring.stl is the middle one. Same ring, keyway, root and tab
on all three — only the strip changes, so they swap in the drum without
touching anything else. **PETG only, hole side UP on the bed**, walls
only, 100% infill.

| strip | printed coils | turns to solid | ratchet teeth | N·mm per turn | N·mm at solid | strain at solid | file |
|---|---|---|---|---|---|---|---|
| 1.4 | 4.7 | 1.39 | 33 (solid) | 35 | 49 | 1.3% | bench/mainspring_t1.4.stl |
| 1.7 | 4.0 | 1.14 | 27 (solid) | 75 | 85 | 1.5% | exports/k1/print/mainspring.stl (the kit) |
| 2.0 | 3.4 | 0.97 | **stop at 20** | 141 | 136 | 1.7% | bench/mainspring_t2.0.stl |

Start with the kit's 1.7. If the escapement will not run on it at full
wind, go to 2.0; if it runs and you want more hours, try 1.4. Report
which ones run, and for how long from solid — that number sizes the
real crown-and-stem winding and tells us whether rev D needs a bigger
drum ratio or a steel strip.

## What bench round 1 found (Oct 2026)

Half a turn of wind loads the spring heavily and runs the bare train
for about 15 seconds. Just under one turn the spring is solid. The
first arbor square (1.6 tall, hollow) let the ratchet climb off, and
the first click did not hold. Both are redesigned; see
docs/log/0027-keyless-works-autopsy.md.

## What to report back next

1. Does the click tick while winding and hold when you let go?
2. With the balance in: how many teeth of wind before it runs, and how
   long does a 12-tooth (half-turn) wind last?
3. Anything that slips, creaks or deforms as the wind builds.

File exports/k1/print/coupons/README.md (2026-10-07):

# K1 calibration coupons — wobble / lockup diagnosis (log 0025)

GENERATED by tools/export_fit_coupons.py — edit that, never this file.

All parts class B: 0.12 layers, 4 walls, 100% infill, outer wall 50 mm/s.
Same X-Y hole compensation as your mainplate — the whole point is to
measure the movement's real fits, so change nothing else.

| part | qty | orientation |
|---|---|---|
| fit_ladder | 1 | flat, ticks up |
| fit_pin | 2 | as exported (disc down); brim 5 |
| mesh_jig | 1 | flat, ticks up |
| mesh_w45, mesh_w60, mesh_w56 | 1 each | as exported (face down, pivot up) |
| mesh_p6, mesh_p8, mesh_p7 | 1 each | as exported (knob down); brim 5 — the
first tooth layers print over the knob edge and may sag; that end is cosmetic |

## Test 1 — pivot fit ladder

Bores are the mainplate's blind train bushing verbatim (Ø2.6 pivot,
3.0 mm engagement), at radial clearance by tick count:

| ticks | 1 | 2 | 3 | 4 | 5 | 6 |
|---|---|---|---|---|---|---|
| clearance | 0.05 | 0.08 | 0.11 | 0.14 | 0.17 | 0.20 |

(6 ticks = 0.20 = the retired pre-measurement guess.)

Flip a pin into each bore, spin the disc, rock it sideways. Record the
tightest tick where the pin (a) drops in under its own weight, (b) spins
freely > 1 s from a flick, (c) re-seats without force after lifting.
That tick's clearance is the new print `pivot_clearance`. Run BOTH pins:
the spread between them is your printer's pivot-to-pivot variance.

*First measurement (Jon's H2C, Aug 2026): tick 3 → 0.11, now in
variants.py. The two pins differed by ~2 ticks — hence the bench rule:
spin-test every arbor, let spares absorb outliers.*

## Test 2 — mesh jig: one wheel + one pinion at a time

Stations by square count next to the wheel bore:
▪ = 45/6 (today's third-fourth, the suspected binder) ·
▪▪ = 60/8 (8-leaf reference — see note below) ·
▪▪▪ = 56/7 (today's minute-third, the higher-torque control)

Wheel pivot in the station's center bore, pinion in a satellite:
1 tick = center distance PINCHED −0.25, 2 = NOMINAL, 3 = SPREAD +0.30.
Jig bores are the measured running fit (0.11), identical everywhere, so
any difference you feel is the mesh, not the fit. Caveat (Jon's catch):
under drive, tooth separation force parks pivots on the loose side of
their bores — a drilled pinch relieves toward nominal, so the pinch
cell tests entering pinched geometry, not sustained pinch.

Drive the WHEEL rim gently with a fingertip; the pinion is the load
(that's the going-train direction). At each satellite, note: smooth /
gritty / catches. The decisive cell is PINCH on the 6-leaf.

Why 60/8 is only a reference: the layout solver shows a 60t third wheel
cannot clear the minute pinion at module 1 (Z3 caps at 45 in this
architecture) — the current train is at the packing limit, so an 8-leaf
fourth pinion is not a drop-in recount.

## Report back

- Tightest free ladder tick (and whether one pin differs from the other).
- The nine mesh-feel cells (3 meshes x pinch/nominal/spread).

Decision table: if 45/6 is fine at NOMINAL and only binds at PINCH,
tightened fits (Test 1's number) should carry rev C. If 45/6 binds even
at nominal while 60/8 is sweet, the leaf count is the wall → rev D
architecture question. If everything binds at pinch including 60/8,
module 1 itself is marginal on FDM → the scale-up conversation reopens.

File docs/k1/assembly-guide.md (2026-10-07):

# Caliber K1 rev C — assembly guide (print variant)

How the pile of printed parts becomes a ticking movement. Every stage
ends with a **gate** — do not pass a stage until its gate passes; every
downstream mystery starts as an upstream skip. Print settings and
support cleanup live in the [printing guide](printing-guide.md); the
part list and orientations in the
[print-kit manifest](../../exports/k1/print/MANIFEST.md).

**Hardware:** M3×18 ×6 + nuts (bridge pillars ×4, cock feet ×2) ·
M3×20 ×3 + nuts (stand feet) · M3 nuts ×16 more (balance timing
weights) ·
*No ×18 in your kit? **×20 + ~2 mm of flat washers under the head** is
an exact substitute (full nut engagement, tip clear of the dial sheet).
**×16 is not** — it catches ~1.4 threads of the nut and will strip.
Bare ×20 threads fine but its tip stands 2.3 proud of the dial face at
r70–74, exactly where the dial sheet lands at the dial stage.* ·
**M2×6 thread-forming ×6** — ONE screw for every M2 hole (bay strap ×2,
click ×1, dial platform ×3) · Super Lube (PTFE grease).

**The M2 screw, specifically:** McMaster-Carr **94209A343** — steel
Phillips pan-head *thread-forming* screw, M2×6, tri-lobular Taptite®
shank with an unthreaded lead-in, pkg of 100 ($9). Every M2 pilot in
the movement is sized for this one part (log 0026), so there is no
"which length goes where." Do NOT substitute sharp-tipped sheet-metal
self-tappers or M2 machine screws: the pilots are Ø1.6–1.8 so a
thread-FORMER can displace its own thread; a cutter shaves the wall and
loosens on the second service, a machine screw won't start. Any true
plastic thread-former (PT / Delta-PT, M2×6, pan head) is an equal
substitute if you have one.

**Tools:** calipers, fine tweezers, hobby knife, small screwdrivers
(#0 Phillips for the M2s), a soft mat. No press needed — every
press-fit here is thumb or gentle-tap.

**Two PLA rules.** Thread-forming M2s into PLA: stop at snug — a
quarter turn past snug strips the boss. And never twist a part off a
press fit; pull straight, or you shear the printed key flats.

Orientation language: "bridge side" is the side with the wave bridge
(z-up in the CAD); "dial side" is the face with the pockets. Assembly
happens bridge-side-up until Stage 7 says otherwise.

---

## Stage 0 — prep and dry fit

1. Deburr every pivot (the Ø2.5 arbor ends) and scrape support witnesses
   flat. Roll each pivot between your fingers feeling for flare.
2. Dry-fit each train arbor's lower pivot in its mainplate bushing —
   it must spin freely with no rock. Fix with light knife scrapes now,
   not under the bridge later.
3. Grease discipline for the whole build: a dab the size of a grain of
   rice per pivot cup or bushing, applied with a toothpick. More is not
   better — PLA + excess grease collects debris.

**Gate:** every arbor spins free in its plate bushing, held vertical by
fingers.

## Stage 1 — the barrel

1. Lay the **mainspring** (PETG, log 0028) into the open **drum**,
   **hole side UP** (the blind hole is in the outer tab's top face).
   Right way up, the strip leaves the inner ring and spirals outward
   **clockwise** as you look into the drum. Upside down it is the other
   hand: winding forces the coils out against the wall instead of
   drawing them in onto the ring, which is how the first spring broke.
2. Turn the spring so its outer **tab** sits just clockwise of the
   small **rib** on the drum's inner wall, nearly touching — the rib
   takes the tangential pull on the tab's counter-clockwise face. It
   will feel loose: a tab on a wall rib has nothing to stop it sliding
   inward (that is what you saw when the old spring "popped off the
   nub"). The cover's pin does that job in step 4.
3. Drop the **barrel_arbor** down the center, its hub rib into the
   **keyway** in the spring's inner ring — the ring is a snug slide
   over the hub and the keyway is the only place the rib goes. Rotate
   the arbor until it drops.
4. **drum_cover** (log 0028: it has a Ø2.5 pin on its underside) onto
   the three wall lugs, **pin into the hole in the spring's tab** —
   turn the cover until the pin finds the hole and the cover lands
   flush at the drum mouth. That pin is the outer anchor; without it
   the first turn of wind pulls the tab off the rib.
5. Grease the plate's barrel recess floor cup, and seat the barrel unit
   in the recess — arbor's lower cup pivot into the blind cup.

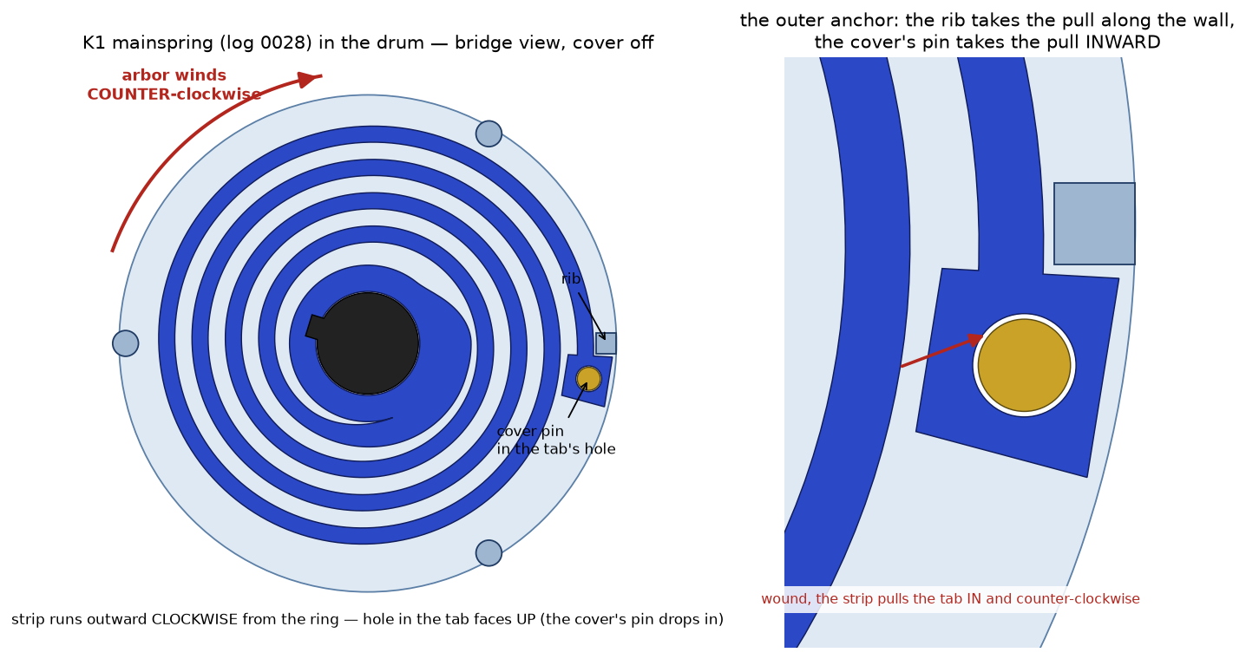
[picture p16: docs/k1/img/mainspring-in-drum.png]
mainspring in the drum, bridge view
   

**Gate:** hold the drum, turn the arbor's square **counter-clockwise**
(looking into the drum from the cover side): resistance grows smoothly
for a turn and springs back when released. Clockwise it should bind
within a fraction of a turn (the coils have nowhere to go but the
wall). If it is the other way round — smooth clockwise, binding
counter-clockwise — the spring is in upside down. The drum itself
spins freely in the recess. *Do not wind to solid here: the arbor
square is 4 mm of PLA and the knob (Stage 5) spreads the load.*

*The arbor's square changed in log 0027: it is now solid and 3.4 tall
(the first was 1.6 tall and hollow, and the ratchet climbed off it
under load). If yours has a square hole in its top, reprint it before
winding.*

## Stage 2 — the going train

Grease each bushing first (rice grain, toothpick).

1. **minute_arbor** — long dial stub DOWN through the central through-bore
   (only arbor that pierces the plate).
2. **third_arbor**, **fourth_arbor** into their blind bushings.
3. **escape_arbor** — bay-cup pivot down into the escapement bay's floor
   cup; the D-seat rides low in the bay.

**Gate:** the chain meshes by eye — drum 60t → minute pinion, minute
wheel → third pinion, third wheel → fourth pinion, fourth wheel → the
escape arbor's 18t pinion up top. Then the test that matters: **one
finger on the drum rim turns the whole train.** Firm is fine — friction
downstream reflects back to the barrel ×48, so this is the stiffest
place to push — but a lock-up here means the mainspring can't run it
either. (Turning from the minute arbor feeling much easier is the same
arithmetic in reverse, not a fix.)

**If it binds from the barrel:** (1) scrape support fuzz off the drum
band's tooth flanks and off the minute wheel's underside — the wheel
overhangs the drum cover by design and any fuzz there drags ×6; (2)
check the drum is fully seated and the cover flush on its lugs; (3)
thin-grease the tooth flanks of the first two meshes, not just pivots;
(4) run in: drive a hundred turns from the minute arbor (the easy
direction), wipe the debris, re-grease, retest. Printed flanks burnish
noticeably in their first minutes. Still locking → the teeth printed
fat and are eating the designed backlash: bump the print variant's
backlash and reprint the minute arbor before fighting it further.

## Stage 3 — the escapement

1. **escape_wheel** presses onto the escape arbor's D-seat — firm push
   until it butts the shoulder (the diameter step above the seat). It
   should need real thumb pressure: that's the drive fit. The short
   pivot protrudes through the wheel below — correct.
   **Which way up matters:** the D-bore lets it go on either face.
   Looking down from the bridge side, the tooth tips must point
   COUNTER-clockwise — the direction the wheel turns. Each tooth's tip
   leads and its sloping body trails behind it. If you printed it the
   way the STL imports, that is bed face DOWN, toward the plate.

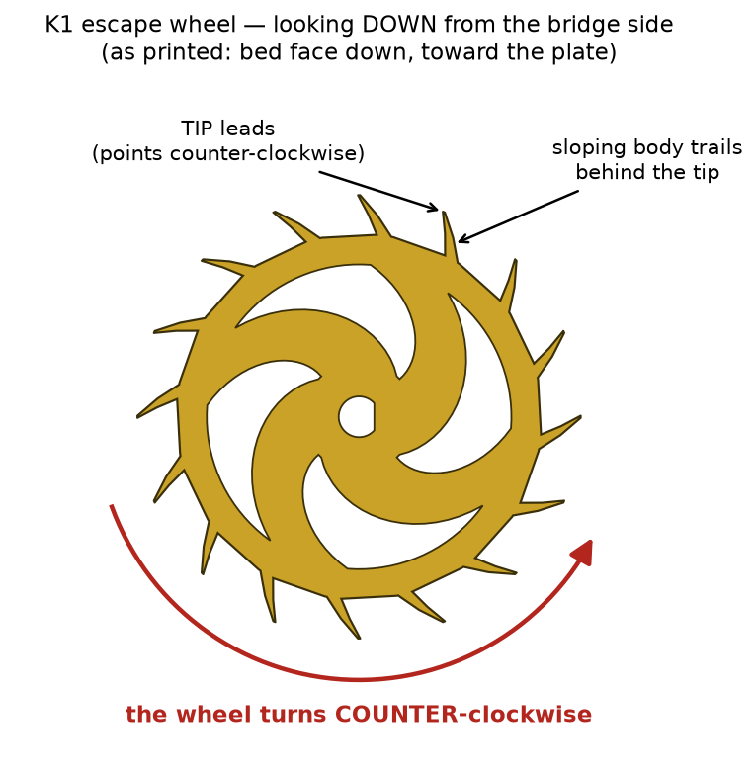
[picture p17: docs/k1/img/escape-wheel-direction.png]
escape wheel seen from the bridge side
   
2. **pallet_fork** — lower (long) pivot into its greased bay-floor cup.
   The fork's horns face the balance side; it can only reach the wheel
   one way.
3. **bay_strap** over the fork's upper pivot (blind cup underneath),
   2× M2×6 into the plate pilots through the strap's two raised foot
   bosses. Snug, not tight. The bosses are what let the 6 mm screw
   run fully home over the shallow near-side pilot, and they hold the
   heads 0.25 mm clear of the balance rim — so if a head ever looks
   like it's touching the balance, the strap is on backwards or a
   boss printed short.

**Gate:** the tweezers test, with two or three teeth of wind on the
barrel. The fork must sit against one banking pin and STAY there — the
wheel is locked on a stone and pulls the fork onto its pin (draw).
Nudge the fork toward centre with tweezers: for the first couple of
degrees it pushes back (the wheel is being forced backward), then it
lets go, the wheel advances half a tooth and throws the fork across to
the other pin, where it locks again. Tick. Nudge it back: tock. Each
nudge = half a pitch (11.25 deg); one full tooth per back-and-forth.
What is NOT correct: the fork flopping between the pins on its own
with the wheel running, or the wheel spinning several teeth free on
one nudge. Both mean a stone is not locking — an old wheel or fork
(see the manifest), a support nub under a stone, or a short print on
the fin. *(Before log 0027 this gate said the escapement would "step
in a rapid buzz" without a balance. It did, and that was the fault.)*

## Stage 4 — the bridge (the four-pivot landing)

1. **Stem first — it cannot go in later** (bench-caught): with the
   bridge in hand, slide the **stem_and_crown** into the tunnel from
   outside, press the **winding_pinion** onto the D-tip from the
   underside until it butts the tunnel's inner face, and snap the
   **stem_clip** into its groove. The pinion press needs finger room
   under the web, which mounting the bridge removes forever.
2. Grease the four train top-pivot holes and the barrel-arbor bearing in
   the bridge web.
3. Rest the **bridge_wave** on its four rim pillars and walk the pivots
   into the cone lead-ins: minute, third, fourth, escape, plus the
   barrel arbor's column into the web bearing. Patience beats force —
   when the bridge sits flush on all four pillars, everything is home.
4. 4× M3×18 down the pillars into the hex nuts in their dial-side
   pockets (no ×18? **×20 + ~2 mm of washers under the head** — see the
   substitution note in Hardware; ×16 strips the nut). Alternate
   corners, snug only.

**Gate:** with the fork out, spin the drum by hand — the train runs
down through the escape wheel freely, no new friction versus Stage 2.
With the fork in, the train must NOT run: the wheel locks on a stone
and stays until the fork is nudged (Stage 3's gate).

## Stage 5 — winding

> **Oct 2026: the crown-and-stem train does not work as drawn** — three
> measured faults, [log 0027](../log/0027-keyless-works-autopsy.md).
> Until it is redesigned, wind by hand at the barrel: fit the bench
> knob (`exports/k1/print/bench/winding_knob.stl`, README beside it)
> in place of the plain ratchet in step 1, leave the crown wheel and
> its stud OUT, and skip steps 3 and 4. Those steps describe the crown
> train as designed and are kept for the redesign.

1. **ratchet** (or the winding knob) onto the barrel arbor's square.
   Its lower half sits in the bridge-top pocket; the rest stands 1.8
   proud. The fit on the square is snug on purpose — press it fully
   down. **Winding turns it COUNTER-clockwise as you look down at the
   bridge**, and the click blocks it clockwise.
2. **click** (PETG): pegs down into their two holes, block into its
   pocket, until the click's flat plate sits on the bridge's top
   surface. M2×6 down the counterbore into the cone-shaped boss under
   the web. **Drive the screw slowly and stop when the head seats.**
   Then check the pawl: push its hooked end outward with a fingernail
   — it should swing about 2 mm on its thin neck and spring back into
   the teeth. If it does not move freely, there is a string of PETG
   bridging the gap between the pawl and the plate; cut it.
   *(The long curved pocket beside the ratchet is the first click's
   arm channel. It stays empty now — the click works above the bridge
   so that nothing limits how far it can lift.)*
   *(Bridges printed before coda 5 rev 8 have a slim Ø4.8 cylinder
   under the web instead of the cone; it twists off under this screw —
   reprint the bridge rather than glue it.)* **If the peg holes are
   scarred** (the pocket prints face-down): twist a Ø2.5 drill bit
   into them by hand before seating the click, stopping at the floor
   — on the cone-boss bridge the peg holes are blind, 1.3 deep.

**Gate (with the knob):** turn it counter-clockwise: the click ticks
over each tooth. Let go: the click holds. **Wind until the spring goes
solid and stop there** — the log-0028 spring is sized so that solid is
inside the PETG's safe strain (the kit's 1.7 strip: about 27 teeth,
1.1 turns; the bench README has the table for the other two strips,
and the 2.0 strip stops at 20 teeth, short of solid). Never force past
solid: everything in the barrel is loaded hardest there.

3. **crown_wheel** flat in its pocket, bevel slots DOWN, spur rim
   meshing the ratchet; press the **crown_stud** through its counterbore
   into the web bore — the mushroom head retains the wheel, flush.
4. The stem is TWO pieces now (coda 5 rev 4 — the one-print stem
   physically could not enter the tunnel; if yours has the pinion
   attached, it is the obsolete part). Order matters:
   1. **stem_and_crown** slides in from OUTSIDE the rim, D-flat tip
      leading, until the crown nears the rim. No force anywhere.
   2. **winding_pinion** presses onto the D-tip from INSIDE (flat side
      toward the tunnel) until it butts the tunnel's inner face —
      that face is its thrust shoulder. Firm thumb press on the D.
   3. Snap the **stem_clip** (PETG) up into the slot inside the tunnel
      run, into the stem's groove.
   Check: the crown spins with light drag and has almost no in-out
   play; its pinion teeth sit in the crown wheel's underside slots.

**Gate:** wind at the crown: crown → crown wheel → ratchet → arbor, the
click ratcheting tooth by tooth. Release the crown — the click HOLDS
the wind, and the train buzzes the charge down through the escapement.
You have a motor. (Hands set by finger later — the crown only winds.)

## Stage 6 — the balance (it ticks)

Let the mainspring down completely first, and make sure the pallet
fork and its strap are in (Stage 3).

Build the balance package on the bench. The **staff** is the balance's
axle: a plain Ø3 rod, 13.8 long — printed, or better, cut from metal
rod (13.6–14.0 is fine; never longer, or the cock pinches it). Square
both ends, take the burr off, and round them very slightly: they are
the bearing surfaces.

The roller, balance wheel and hairspring **grip the staff by
friction** — they must turn with it, not on it. They should press on
with firm thumb pressure. If one will not start, open its hole a
little at a time with a round needle file or rolled sandpaper and try
again; do not drill it out to 3.0, and do not force it (the hub
splits). If one ends up loose: a drop of superglue for the roller or
the wheel, but leave the hairspring's collet as a friction fit — it
is how the beat is adjusted.

Measure each seat height **from the staff's lower tip**:

| part | seats at | orientation |
|---|---|---|
| roller | tier bottom **1.9 mm** up | crescent tier DOWN, impulse pin up |
| balance_wheel | ring bottom **5.3 mm** up | nut pockets UP |
| hairspring collet | **9.4 mm** up | stud tab reaching outward |

1. Press an **M3 nut** into each of the 16 hex pockets in the balance
   wheel's rim (flat-nose pliers or a small vise) until it sits below
   the rim's face. Nothing may stand proud of the rim on either side:
   the hairspring passes 0.7 mm above it and the pallet strap 0.5 mm
   below. A nut that is loose gets a drop of superglue.
2. Press roller, wheel, hairspring onto the staff at those heights.
3. Grease the bay's balance cup. Lower the package in — staff tip in
   the cup, and rotate so the **impulse pin sits inside the fork's
   slot** (pin between the horns; the guard finger rides the crescent).
4. A dab of grease in the blind cup under the **balance_cock**'s arm —
   its floor is the staff's upper endstone.
5. Cock over: cup onto the staff's top end, the hairspring's stud ring
   dropping over the cock's hanging stud post. 2× M3×18 through the
   feet columns into their dial-side nuts (same ×20-plus-washers
   substitute as the bridge pillars).
6. Lift the balance with tweezers: it should rise about 0.3 mm and
   drop back. No play at all = the staff is too long; file 0.1–0.2 off.

**Gate:** the first tick. Wind 6 teeth to start and add 6 at a time —
too much shows as the balance swinging very wide and knocking at the
ends of its swing; too little, it stalls. Note the teeth it first runs
on: that number sizes the real winding mechanism. The balance should take up
oscillation and run — a stately ~1 s beat (16t wheel, 0.53 Hz). If it
stalls: check endshake (balance must have visible up-down float, not
pinched by the cock), then beat (below).

**Beat adjustment:** at rest with zero wind, the fork should sit midway
between its bankings. If it rests against one pin, grip the balance
rim, and rotate the hairspring **collet** on the staff (the slit makes
it a friction clutch) a few degrees, and retest. Even "tick—tock"
spacing by ear is the goal.

## Stage 7 — the dial side (time appears)

Flip the movement — rest it bridge-down on a soft mat (the cock and
bridge take the weight; the balance survives this, but don't press).

1. **Posts first** (the axles): **center_post** (Ø3) into the center
   bore; the six **arbor posts** (Ø2 — printed or your cut brass pins)
   into their bores: motion, w1, w2, disc, i1, i2. Press flush-bottomed;
   tips stand 0.7 proud of the face — they locate everything later.
2. **transfer_pinion** (PETG): its slit collet presses onto the minute
   arbor's round stub. This friction joint IS hand-setting — running
   torque carries, setting torque slips.
3. **transfer_idler** ×2 onto posts i1/i2, meshing pinion→idler→idler.
4. **motion_arbor** onto its post.
5. **cannon** over the center post — its deep gears (12t + 16t transfer
   tail) go down into the pockets; the 16t meshes the second idler.
6. **hour_wheel** sleeves over the cannon's pipe — 40t meshing the
   motion arbor's 10t, integral 24t moon pinion riding above.
7. Moon train: **moon_w2** onto its post, **moon_w1** onto its post
   (36t meshing the hour pipe's 24t), then the **moon_disc** — and set
   the moons to today's phase before covering (you can nudge it through
   the window later, but now is easy).
8. **dial_platform** over everything, located by the six post tips,
   3× M2×6 into the plate (5.5 mm pilots — the same screw as
   everywhere). It closes every pocket — nothing should rattle.
9. **dial_sheet** onto the platform, located by the same post tips,
   center pierced by the hour pipe.
10. Hands at **12:00 both**: hour_hand onto the hour pipe's seat,
    minute_hand onto the cannon's flat seat. Press straight down.

**Gate:** turn the minute hand gently clockwise — it slips at the
transfer collet with silky resistance, the hour hand follows at 1/12
speed, and nothing inside clicks or catches. Set to the current time.

## Stage 8 — stand it up and regulate

1. 3× **stand_foot** at the plate rim, M3×20 + nuts.
2. Full wind. Set time. Let it run.
3. **Rate trim** (the point of the timing screws): time it against your
   phone over an hour. Running slow → shorter/lighter rim screws (less
   inertia = faster). Running fast → longer/heavier screws. Always move
   opposite pairs together to keep the balance poised. Expect to trim —
   every spool of filament has its own stiffness; the screws exist
   because of that.

**Final gate:** a full wind runs the movement down over hours, not
minutes, keeping visible time against your phone. Welcome to horology.

---

## Serviceability (by design — use it)

- **Fork out:** 2× M2 off the bay strap, lift the strap, lift the fork.
  The balance and cock stay put.
- **Balance out:** 2× M3 off the cock, lift the package by the cock.
- **Winding jam:** the click's M2 releases the whole click for
  inspection without touching the bridge.
- **Power down before service:** hold the crown firm, lift the click
  with tweezers, and let the crown unwind slowly through your fingers.
  Never pull the bridge with the spring charged.

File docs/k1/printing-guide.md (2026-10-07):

# Caliber K1 — FDM printing guide (Bambu Studio, H2C)

Settings for printing rev C parts from `exports/k1/print/`. These are watch
parts: module 0.6–1.0 gears with sub-millimeter teeth and press-fit bores,
so dimensional accuracy matters more than speed. Read the calibration note
before the first real run.

## H2C quick-set (Bambu Studio)

**Nozzle: 0.4 mm — install/confirm this and keep it for the whole build.**
The smallest teeth in the movement are the module-0.6 moon-train gears
(~0.9 mm thick at the pitch line), which a 0.4 nozzle renders as ~2 clean
perimeters — proven at this scale. A 0.2 nozzle would sharpen those flanks
but roughly doubles print time and makes every part more fragile; not worth
it for a functional first build. A **standard steel** nozzle is fine —
hardened is only for abrasive (carbon/glass-filled) filament, which we
don't use. *(Later, if you want jewelry-grade dial gears, re-printing only
the moon train with a 0.2 nozzle is the upgrade — recalibrate first.)*

**Machine / plate**

| field | value |
|---|---|
| Nozzle | **0.4 mm**, standard steel |
| Build plate | **Textured PEI** — safe for both PLA and PETG (smooth PEI grips PETG hard enough to chip) |
| Flow dynamics / pressure advance | Auto-calibrate **ON** (leave Bambu's) |
| Auto bed leveling | **ON** every print — matters for the Ø170 flat parts |

**PLA** — start from the **Bambu PLA Basic** profile, then:

| field | value |
|---|---|
| Nozzle temp | 220 °C first layer / 215 °C rest |
| Bed temp | 55 °C |
| Layer height | 0.20 mm plates · 0.12 mm gears |
| Walls / top / bottom | 4 / 4 / 4 |
| Infill | 20% gyroid plate · **40% gyroid bridge (5 top/bottom layers)** · 100% (gears & small parts) |
| Outer-wall speed | 50 mm/s (slow flanks = clean teeth) |
| Brim | 5 mm on the Ø170 parts |
| Supports | Organic (tree), pockets/overhangs only |

**PETG** — select the **Bambu PETG HF** profile (matches your spool) and
**leave its temps and fan as tuned by Bambu**; only change:

| field | value |
|---|---|
| Layer height | 0.12 mm |
| Walls | 4 (hairspring/mainspring are intentionally thin — see Class C) |
| Plate | Textured PEI + a glue-stick release layer |

**Before the real parts:** run Bambu Studio's built-in **flow-rate and
pressure-advance calibration** once per filament (~10 min). It's what saves
you the hairspring and gear reprints.

> Confirm the exact profile *names* and any H2C-specific fields (dual-nozzle
> / AMS options) in your own Bambu Studio — the H2C is new enough that I'd
> rather you verify the machine profile than take my word for a menu label.
> The **values** above are the targets regardless of what the profile is called.

## The one thing that will bite you: clearances are already baked in

The geometry already includes running clearance (0.11 mm on every print
pivot — fit-ladder-measured on the H2C, log 0025; the original 0.20 guess
is what made the first train wobble and lock) and gear backlash
(0.30 × module). **Do not add more.** In particular:

- **X-Y hole/contour compensation:** leave Bambu's default *as-is* for the
  first print, then measure and calibrate. Do **not** stack your own hole
  expansion on top of the designed clearance — the bores will come out
  loose and the gears will have lash.
- Your printer's real dimensional offset is unknown until you measure. That
  is the entire point of printing the mainplate first: it is the reference.

**First-print calibration loop:** print the mainplate → with calipers,
measure against these designed values (they already include running
clearance):

- a train pivot bushing (third/fourth positions): **Ø2.82**
- the central minute through-bore: **Ø3.02**
- the barrel recess: **Ø58.0**
- plate thickness: **6.5**

FDM typically comes out with holes *slightly under* nominal (elephant-foot
and over-extrusion pull them in). If yours are consistently ~0.1–0.2 mm
small, add that as X-Y hole compensation and record it in your build log.
Only then print mating parts.

**Train locking up / wheels wobbling?** Print the diagnosis kit in
`exports/k1/print/coupons/` (generated by `tools/export_fit_coupons.py`)
before changing any tolerance: a six-step pivot-fit ladder that measures
the right `pivot_clearance` for your printer, and a mesh jig that tells
fit problems apart from tooth-geometry problems (log 0025). Its README
has the protocol.

## Global settings (all parts, PLA)

| setting | value | why |
|---|---|---|
| Nozzle | 0.4 mm | 0.2 would be finer for teeth but far slower; 0.4 proven at this module |
| Layer height | **0.12 mm** gears/arbors, **0.20 mm** plate/bridge | teeth need the resolution; the big flat parts don't |
| Walls (perimeters) | **4** | small parts become nearly solid; teeth print as walls, not infill |
| Top/bottom layers | 4 / 4 | seals faces on the flat parts |
| Infill | **100%** small parts, **20% gyroid** plate, **40% gyroid** bridge (5 top/bottom) | gears must be solid; skins + 4 walls carry the flats — an earlier manifest note said bridge 100%, retired: it bought print hours, not stiffness |
| Nozzle temp | 210 °C (first layer 220) | standard PLA |
| Bed temp | 55 °C | Bambu textured PEI |
| Print speed | **50 mm/s** outer walls, default elsewhere | slow outer walls = clean teeth |
| Seam | Aligned, tucked to a bore or spoke | keeps the seam off tooth flanks |

## Per-part-class profiles

**Class A — big flat plates** (`mainplate`, `bridge_DRAFT`, `dial_platform`)
- 0.20 mm layers, 20% gyroid, **brim 5 mm** (warp control on the Ø170 disc).
- Mainplate: **dial face DOWN**, tree/organic supports **in the dial
  pockets only** (not under the whole part). Bridge: **top face DOWN**.
- First layer slow (`≤ 30 mm/s`) and a clean bed — adhesion is everything
  on a part this wide.

**Class B — gears, arbors, wheels** (train arbors, escape wheel, crown
wheel, ratchet, motion/moon wheels, roller, balance wheel)
- **0.12 mm layers, 4 walls, 100% infill, 50 mm/s outer walls.**
- Arbors print **vertical** (small pivot up), **brim on** — they're tall and
  thin. Flat wheels print flat.
- **Arbors need painted supports** — each one is a stack of discs on a thin
  stem, and every disc underside is a horizontal overhang (confirmed the hard
  way: unsupported, the wheels spaghetti). Use Tree (manual) and paint ONLY
  under discs with clear air to the plate:
  - `minute_arbor`: under the 14t pinion + under the 80t wheel outside the
    pinion's footprint
  - `third_arbor`: **print INVERTED (top pivot down, pinion low)** —
    upright, its 8t pinion hangs 1.0 mm over the Ø50 wheel where the
    no-paint rule applies, and that sag ring lost the whole pinion
    twice (worse at 0.16 layers). Inverted it matches the fourth's
    recipe: paint under the 8t pinion + under the 48t wheel outside
    the pinion footprint; deburr the top pivot's end face after
  - `fourth_arbor`: under the 8t pinion + under the 36t wheel outside the
    pinion's footprint
  - `escape_arbor`: under the 18t pinion (the trees also brace the tall post)
  - **Never** paint a ring that hovers ≤1 mm above the disc below it (wheel
    directly over its pinion) — no room to remove support; the slight sag
    self-heals and fuzz is fine. Collar steps ≤0.5 mm need nothing.
  - Anti-scar settings: top Z distance 0.2, top interface layers 2, top
    interface **spacing 0.4–0.5**, support/object XY distance 0.4,
    on-build-plate only. (A dense 0.2 interface WELDS into matted fuzz —
    proven on the first arbor batch. Loose interface peels as a sheet;
    the supported face only needs to be blob-free, not smooth.)
  - Put the arbors on their own plate — a toppled arbor shouldn't take the
    flat parts with it.
- **Cup-shaped parts print closed-face DOWN, mouth UP** (the drum: floor
  down). The interior — the surface the mainspring rides — then prints
  clean with zero support; auto-tree ≥50° catches only the outer gear-band
  ledge and cover lugs. Band-down buries the interior in support.
- Cleanup of supported faces: brass/nylon brush wheel in a rotary tool at
  the LOWEST speed (PLA melts at dremel speeds), or a knife scrape.
  Stay off tooth flanks.
- Print the **spares** the manifest calls for. Small gears are cheap and
  bench tuning consumes escape wheels and forks.

**Class C — flexures & grips (PETG ONLY** — PLA creeps and snaps here)
`mainspring`, `hairspring`, `click`, `transfer_pinion`, `stem_clip`
- PETG-HF: nozzle ~250 °C, bed 70 °C, **cooling 50%** (PETG wants less than
  PLA), 0.12 mm layers.
- Mainspring: **hole side up** on the bed (the blind hole in the outer
  tab), walls only (4 walls cover the 1.7 strip; let any remainder be gap
  fill, not infill), no supports. It is the one part whose hand matters —
  printed hole-down it comes out the mirror image and winds the wrong way
  (log 0028). Print all three strips in exports/k1/print/bench/ if you are
  tuning torque. The drum_cover (Class B) reprints with it: its pin is the
  spring's outer anchor.
- Hairspring is a 0.45 mm single-line wall — do a flow calibration first;
  print 3, keep the best.
- Mainspring: 100% infill, flat as-printed spiral; print 2 spares.

**Class D — register pins** (`center_post`, `arbor_post_*`, `balance_staff`)
- Printable in PLA vertical, but these are the parts to swap for **metal**:
  Ø3 and Ø2 steel rod / dowel pin cut to length. The bores are sized for a
  press fit either way. This is the cheapest "feels like a real movement"
  upgrade.

## First-print sequence (recommended)

1. **`mainplate.stl` alone** — longest print; go do other things.
   Measure it (calibration loop above) before printing anything that mates.
2. **`bridge_DRAFT.stl`** + the barrel group (`drum`, `drum_cover`,
   `barrel_arbor`, `ratchet`, `crown_wheel`, `crown_stud`) on one plate.
   Fit the bridge to the measured mainplate — check the four pillars seat
   and the stem tunnel lines up.
3. Train arbors + escapement set (with spares).
4. Balance group + dial-side gears + platform + feet.
5. PETG parts (Class C) once your PETG spool arrives.

Hold the final **wave bridge** and the **decorated balance cock** — the
decorative pass replaces those; `bridge_DRAFT` is only to prove the fit.

## Hardware (not printed — from the manifest)

M3×18 ×6 + nuts (bridge pillars, cock feet), M3×20 ×3 + nuts (stand feet),
M3 nuts ×16 (balance timing weights, pressed flush into the rim — they
set the 16t rate and are the bench rate trim), M2×6 thread-forming ×6 — McMaster 94209A343, ONE screw
for strap, click and platform (log 0026), Super Lube (PTFE
grease) on every pivot before assembly. *(An earlier revision said M3×8 for
the pillars — too short to reach the dial-side nut pockets through the
17.7 mm stack; the ×8s belong in the balance rim.)*

Everything printed? The [assembly guide](assembly-guide.md) takes it from
here — stage by stage, each with its own inspection gate.

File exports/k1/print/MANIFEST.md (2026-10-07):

# Caliber K1 rev C — print kit (movement r6)

Assembly, stage by stage with inspection gates:
[docs/k1/assembly-guide.md](../../docs/k1/assembly-guide.md)

## Hardware (not printed)

- **M3 + nuts** (hex nuts drop into dial-side pockets, 2.4 deep): **M3×18 ×6**
  (bridge pillars ×4, cock feet ×2 — stack is 17.7 minus the pocket) and
  **M3×20 ×3** (stand feet — plate 6.5 + foot 14). *An earlier note said
  M3×8 ×7 — that was wrong; ×8 doesn't reach any nut in this stack.*
- **M2×6 thread-forming ×6** — ONE screw for every M2 hole (bay strap ×2,
  click ×1, dial platform ×3): **McMaster-Carr 94209A343** (steel Phillips
  pan-head Taptite®, tri-lobular thread-former, pkg 100). Every M2 pilot is
  sized to it (log 0026). Not sheet-metal self-tappers, not machine screws.
- **M3 hex nuts ×16** — balance timing weights, pressed flush into the
  pockets in the balance wheel's rim (on top of the 9 nuts the M3 screws
  use). They set the 0.53 Hz rate and are the bench rate-trim: take them
  out in opposite pairs to speed the beat. *(Six M3×8 screws were
  specified here until log 0027 — they cannot fit: the rim has 0.7 mm
  of air above it and 0.5 below.)*
- Super Lube (PTFE grease) on every pivot at assembly.

## Print profiles (Bambu Studio; 0.4 nozzle, textured PEI)

| class | parts | settings |
|---|---|---|
| **A** — big flats | mainplate, bridge_wave, dial_platform, dial_sheet | 0.20 layers, 20% gyroid (bridge_wave **40% gyroid, 5 top/bottom layers** — was 100%: skins + 4 walls do the work on a 3mm plate; washer under any M3 head that dimples its boss), walls 4/4/4, brim 5 |
| **B** — gears, arbors, small | everything not listed elsewhere | 0.12 layers, 4 walls, **100% infill**, outer wall 50 mm/s, first layer 220°/rest 215°, bed 55°. *Exception: the four TRAIN ARBORS may run **40% gyroid** (+0.16 layers if speed matters) — at 4 walls everything Ø≤3.4 is solid wall anyway; only the wheel webs change. balance_wheel stays 100% (its infill is timing mass) and escape_wheel stays 100% (all walls regardless)* |
| **C** — flexures | mainspring, hairspring, click, transfer_pinion, stem_clip | **PETG** (Bambu PETG HF profile), 0.12 layers, 4 walls |
| **D** — register pins | center_post, arbor_post_*, balance_staff | PLA vertical, or swap for Ø3/Ø2 steel rod (press-fit either way) |

**Supports — the anti-scar recipe (learned the hard way on the first arbor batch):**
Tree (**manual**), painted ONLY where a row below says so. Top Z distance **0.2**,
top interface layers **2**, top interface **spacing 0.4–0.5** (a dense 0.2 interface
WELDS to the part), support/object XY distance **0.4**, on build plate only.
Never support a ring hovering ≤1 mm above the disc below it — no room to remove;
the sag self-heals. Cup-shaped parts print closed-face DOWN so the interior
needs no support at all.

**THE ARBOR ORIENTATION RULE (in plain sight, after three bench rounds
of breakage): big wheel HIGH, longest skinny feature at the plate,
small pivot tips UP.** Every arbor break so far was a small feature
printed at the BOTTOM underneath a big disc. Self-check on the print:
support scarring belongs only on disc UNDERSIDES, in rings; a fully
scarred wheel face with a mangled tip at its center = the part printed
upside-down. NOTE: "pinion up" is NOT the rule — it happens to be
right for third(inverted) and escape, and WRONG for minute and fourth.

**The sunk-arbor trap (cost two third-arbor prints):** an arbor must
stand on the tiny O2.5 end of its shaft with EVERY gear disc floating
mid-air on its painted trees. "Lay on face" / auto-orient picks the big
wheel face, which rests the wheel on the bed and sinks the shaft BELOW
the plate — the slicer silently discards everything underground and
prints a bare gear. The subtler form (caught by Jon's side-view
screenshot): ROTATING a part in Bambu pivots it about its center and
leaves it partially sunk — always click "Place on plate" after any
rotation. The check is a number, not a vibe: the third arbor's wheel
underside hovers exactly 3.65 above the plate (collar 0.35 + pivot
3.3); a shaft visibly crossing the plate surface is being amputated.

**Brim:** type *Outer brim only*, width 5, gap 0.1 — on every vertical part and
the Class A flats. **Elephant-foot compensation ≥0.15** on; deburr and dry-fit
every plate-end pivot in its bushing before assembly (0.11 mm running clearance
— ladder-measured, log 0025 — is the whole budget, and printed pivots vary
~±0.03 r part-to-part: spin-test each arbor, spares absorb the outliers).

## Parts

| part | qty | cls | orientation / supports |
|---|---|---|---|
| mainplate | 1 | A | dial face DOWN; tree supports in the dial pockets only. **Measure it before printing mates:** bushing Ø2.82, center bore Ø3.02, barrel recess Ø58.0, thickness 6.5 → set X-Y hole comp to the shortfall |
| drum | 1 | B | **floor DOWN, cup mouth UP** — the interior (where the spring rides) prints clean with zero support; auto-tree ≥50° catches the outside gear-band ledge + 3 cover lugs. *(Band-down buries the interior in support — don't.)* |
| drum_cover | 1 | B | flat, PIN UP (flat face on the plate), no supports. **Re-cut in log 0028: a O2.5 pin on the underside drops into the mainspring tab's hole — it is what keeps the spring's outer end on the rib.** An old flat cover lets the spring slide off the rib at the first turn |
| barrel_arbor | 1 | B | vertical, square end UP; brim. The square is SOLID and 3.4 tall since log 0027 (the hollow 1.6 one let the ratchet climb off under half a turn of spring) — it stands 1.7 above the bridge, inside the ratchet |
| mainspring | 1 | C | **PETG ONLY**, flat, HOLE SIDE UP on the bed, 100% infill, walls only (the 1.7 strip is 4 walls; let any remainder be gap fill). **Re-cut in log 0028 — discard the 2.2 strip with the inner C-loop: it was the other hand and it broke.** This one is a solid inner ring keyed to the arbor rib, a tapered root, and a tab that sits against the drum rib under the cover's pin (reprint the cover); it packs solid at 1.14 turns and cannot be overwound. Two more strip thicknesses (1.4, 2.0) are in bench/ — print all three, the bench picks; picture docs/k1/img/mainspring-in-drum.png |
| ratchet | 1 | B | flat, the face with the CHAMFERED bore mouth on the plate. 3.45 thick since log 0027: the top 1.8 stands proud of the bridge, where the click now works. Bore is a snug 4.15 on the 4.0 square — if it will not start, ease the mouth with a knife; do not open the whole bore |
| click | 1 | C | **PETG ONLY** — it is a pull-pawl with a 0.8 flexure neck (log 0027). Print FLAT SIDE DOWN, pegs UP: the plate and the curved pawl both lie on the bed, no supports. Afterwards the pawl must swing freely on its neck — cut any strings in the 0.8 gap between pawl and plate. Print 2 |
| crown_wheel | 1 | B | slots UP (top face down) |
| crown_stud | 1 | B | head DOWN |
| stem_and_crown | 1 | B | crown face DOWN, axis vertical (no pinion on it since coda 5 rev 4 — no supports needed beyond the brim) |
| winding_pinion | 1 | B | flat. **Assembly order matters:** stem in from OUTSIDE first, then this presses onto the D-tip from inside until it butts the tunnel face, then the C-clip |
| stem_clip | 1 | C | PETG preferred; flat; print 3 |
| minute_arbor | 2 | B | vertical, **long dial stub at the PLATE, 56t wheel HIGH, short top pivot UP** (Jon's bench, coda 5 rev 7: printed pinion-up = upside-down, the wheel face rode a full support bed and the top pivot — the bridge-shelf thrust tip — printed at the bottom and snapped). Brim. Paint under the 10-leaf pinion + under the 56t wheel *outside the pinion's footprint*; skip the ring directly over the pinion |
| third_arbor | 2 | B | vertical, **INVERTED: top pivot DOWN** (7-leaf pinion low, 45t wheel high). Shaft-down, this is the ONLY arbor whose biggest disc (the O47 wheel) lands directly on the naked O2.5 bottom column — the nozzle wobbles the flagpole while sweeping the big disc and the junction bonds one layer deep (leaned 5 deg and snapped at a touch, Jon's bench; every other arbor stacks a small pinion on its column first, and all proved sturdy). Inverted = the fourth's topology: 2.0 column, widening neck, pinion on plate trees, wheel on a braced core. Brim. Paint under the pinion + under the wheel outside the pinion footprint. Deburr the plate-side pivot end face (the shelf thrust face) |
| fourth_arbor | 2 | B | vertical, **long lower shaft at the PLATE, 36t wheel HIGH, short top pivot UP** (NOT pinion-up — that flips it); brim. Paint under the 6-leaf pinion + under the 36t wheel outside the pinion footprint |
| escape_arbor | 2 | B | vertical, bay pivot DOWN; brim. Paint under the 18t pinion — the trees double as bracing for the tall post |
| escape_wheel | 3 | B | flat. **Teeth re-cut in log 0027 — discard every earlier wheel.** It goes on ONE way up: looking down from the bridge side, the tooth TIPS POINT COUNTER-CLOCKWISE — the way the wheel turns, like a saw blade's teeth pointing into the cut; each tip overhangs its own root (picture: docs/k1/img/escape-wheel-direction.png). Printed as exported, that is bed face DOWN toward the plate. Earlier wheels have no overhang. Upside down, or an old wheel, has no lock and the fork flops |
| pallet_fork | 3 | B | **Fork re-cut twice in log 0027 — discard every earlier fork** (two straight prongs = the oldest; flared horns with a POINTED finger underneath = current; the stones changed with the escape wheel, so print the fork and the wheel together from the same export). The pointed guard finger under the horn end is thin: support it like the rest of the underside and peel gently. Body flat, **long (2.0) pivot DOWN** — the body hovers 2 mm on the pivot tip. Paint the ENTIRE body underside; never the pivot. Peel supports away from the pivot, holding the body. The stone fins are the working faces: no support contact, no cleanup sanding |
| bay_strap | 2 | B | flat |
| roller | 2 | B | flat, crescent side down. The impulse pin is O1.8 since log 0027 (was O2.5) — it and the fork end were redesigned together; an old roller will not enter a new fork |
| balance_staff | 1 | D | vertical; or cut 13.8 from Ø3 metal rod (13.6-14.0; never longer), both ends squared, deburred and slightly rounded |
| balance_wheel | 1 | B | flat, **hex pockets UP**, no supports; then press an M3 nut into each of the 16 pockets until it is below the rim's face — NOTHING may stand proud of either face (the hairspring passes 0.7 above, the pallet strap 0.5 below). A loose nut gets a drop of superglue; the small hole under each is for pushing it back out |
| hairspring | 1 | C | **PETG ONLY** — flat; 0.45 walls = single-line: tune flow first; print 3 spares |
| balance_cock | 1 | B | arm flat, columns UP; paint supports under the stud post. The blind cup in the arm is the staff's upper bearing AND its endstone (printed since log 0027 — no cabochon): keep supports out of it and check its floor is clean |
| stand_foot | 3 | B | vertical |
| center_post | 1 | D | vertical; or Ø3 steel rod |
| cannon | 1 | B | pipe vertical, hand-seat UP |
| hour_wheel | 1 | B | pipe vertical |
| motion_arbor | 1 | B | vertical |
| moon_w1 | 1 | B | flat |
| moon_w2 | 1 | B | vertical shaft |
| moon_disc | 1 | B | moons DOWN (two-color swap at 0.3 if using AMS) |
| transfer_pinion | 1 | C | PETG preferred; flat; slit collet is the hand-setting slip; print 2 |
| transfer_idler | 2 | B | flat |
| dial_platform | 1 | A | flat, proud face down |
| dial_sheet | 1 | A | face color! face DOWN; engraved markers paint-fill at the bench |
| minute_hand | 2 | B | hand color; flat |
| hour_hand | 2 | B | hand color; flat |
| bridge_wave | 1 | A | show face — pick a color! SHOW FACE DOWN (pillars up); 40% gyroid, 5 top/bottom (profile A); supports only in the ratchet pocket + stem tunnel; brim. The click screw's under-web boss is a CONE (root O11 on the web, O6 tip — coda 5 rev 8): it points up in this orientation and needs no support |
| arbor_post_motion | 1 | D | vertical; or Ø2 steel pin |
| arbor_post_w1 | 1 | D | vertical; or Ø2 steel pin |
| arbor_post_w2 | 1 | D | vertical; or Ø2 steel pin |
| arbor_post_disc | 1 | D | vertical; or Ø2 steel pin |
| arbor_post_i1 | 1 | D | vertical; or Ø2 steel pin |
| arbor_post_i2 | 1 | D | vertical; or Ø2 steel pin |

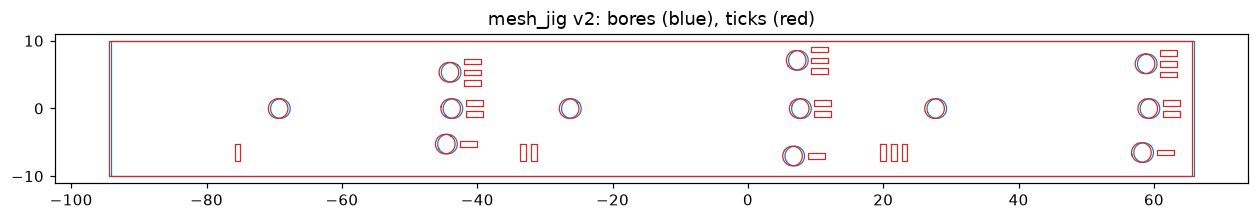
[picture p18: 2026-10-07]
exports/k1/print/coupons/check_mesh_jig.png

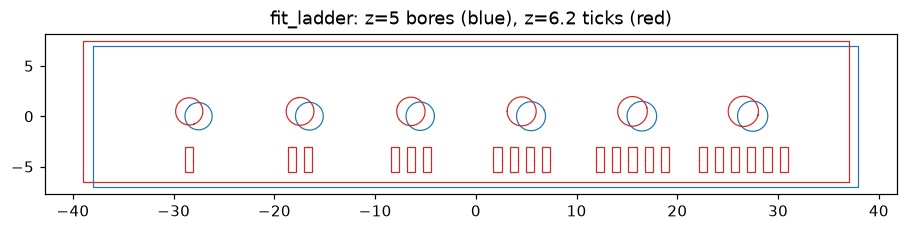
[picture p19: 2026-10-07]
exports/k1/print/coupons/check_fit_ladder.png

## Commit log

2026-10-07 K1 rev C bench rounds: sixteen teeth through the mainspring (logs 0024-0028)
    Four months of bench-driven fixes to the plastic K1, each one measured
    before it was redesigned:
    - 0024 sixteen teeth: escape wheel re-cut for the nozzle.
    - 0025 wobble and the packing limit: pivot_clearance set to 0.11 by
    coupon (tools/export_fit_coupons.py); the train is at the module-1
    packing limit (Z3 <= 45), the mesh was never guilty.
    - 0026 the stones meet the tips: escapement rebuilt on the kinematic
    probe (tools/probe_escapement.py), endshake architecture, one M2
    screw for the movement, click and winding fidelity passes.
    - 0027 keyless works autopsy: crown/stem faults measured and recorded
    as str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
    [balance_cock.stl, balance_wheel.stl, barrel_arbor.stl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]
2026-10-07 docs: handoff prompt for the 36 mm metal base caliber
    Everything a fresh conversation needs to design the open metal caliber:
    goal and the working definition of "open", decisions made Oct 7 2026
    (36 mm, 4 Hz, ETA 2824-class regulating assortment for v1), the honest
    assessment of K1 as a watch caliber, what transfers from the plastic
    work and what does not, the process lessons, a five-phase plan, open
    decisions, and the branch/worktree arrangement so the plastic K1 and
    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
2026-10-07 docs: handoff todos — STEP out of git, spline gear flanks, scratch 3mf
